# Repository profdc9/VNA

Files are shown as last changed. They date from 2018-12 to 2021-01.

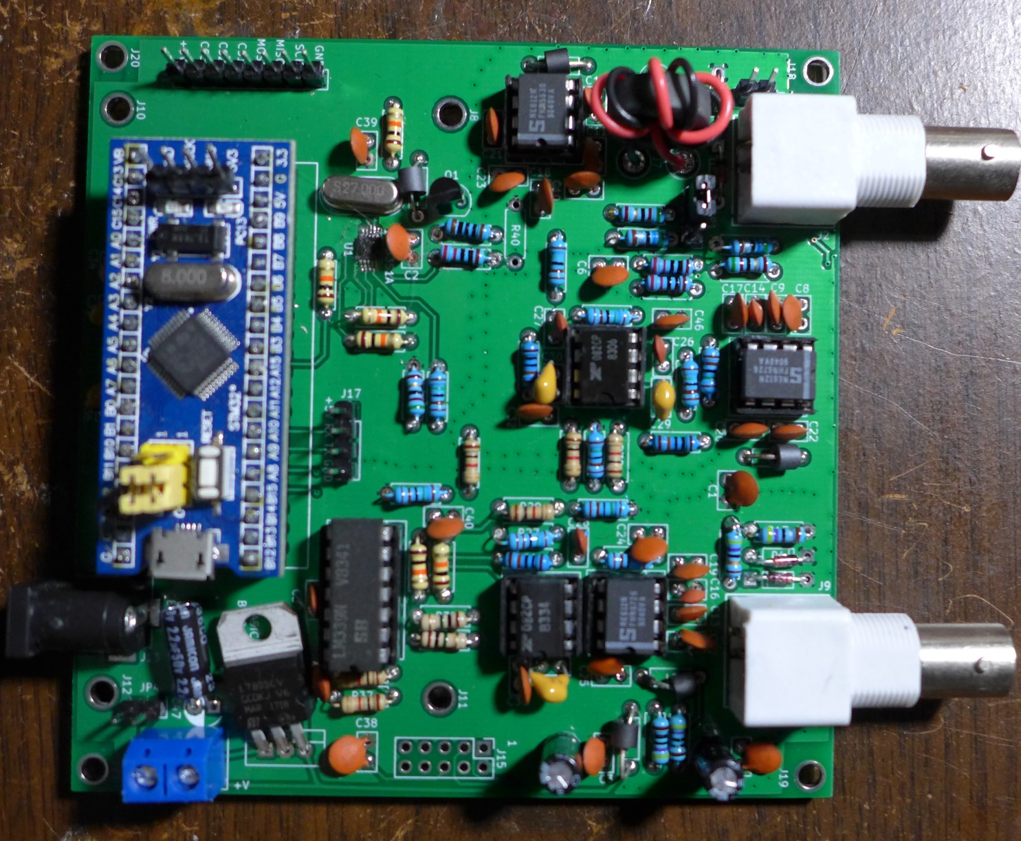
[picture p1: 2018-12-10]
doc/vna-assembled-board.jpg

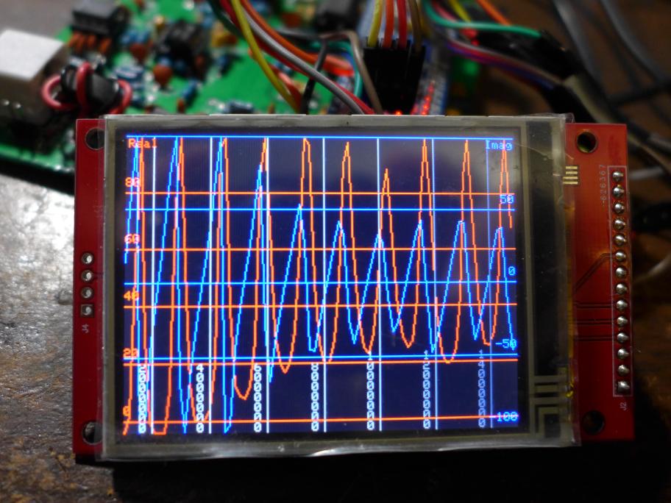
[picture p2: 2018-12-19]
doc/vna-impedance-display.jpg

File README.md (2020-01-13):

This a project to create a Vector Network Analyzer based on the EU1KY antenna tuner that can be reconfigured for different needs.  This material is copyrighted by Daniel Marks (KW4TI) and licensed under the Creative Commons License CC-BY-SA 4.0.  The software is licensed under the zlib license.  These are open source licenses that permit commercial use, modification and redistribution with attribution, and require licensees to assume all risk for using the copyrighted materials.

Currently what is on this github are the Kicad files for the VNA and the software.  The software uses the "stm32duino" extension to the Arduino IDE.  The Arduino IDE can be downloaded from

https://www.arduino.cc/en/Main/Software

The stm32duino software can be installed using the instructions on the stm32duino web site

https://github.com/rogerclarkmelbourne/Arduino_STM32/wiki/Installation

which involves (at this time) downloading the git archive for the stm32duino and placing it under the "hardware" folder in your Arduino folder.

There are several Arduino libraries that are required for the SI5351A frequency synthesizer chip, ILI9341 TFT display module, and XPT2046 touchscreen controller.  These are provided for your use under the "libraries" directory of this archive, but may not be the most recent versions.  You could copy these directories into the "libraries" folder in your Arduino directory.

---------------------------------

The VNA may be used with or without a touchscreen.  If a touchscreen it used, it should be compiled with the "VNA_TOUCHSCREEN" defined in VNA.h.  If you do not have a touchscreen, you can ground the pin PB13 and it will start up without a touchscreen, only appearing a USB CDC serial port device.  You can then type "HELP" to see the list of commands.

The touchscreen used is a 2.8" touchscreen with a SPI interface to the ILI9341 and XPT2046.  These are commonly available at a low price.  To connect it to the SPI interface connector header "J1" on the board, use a 14 pin IDC ribbon cable.

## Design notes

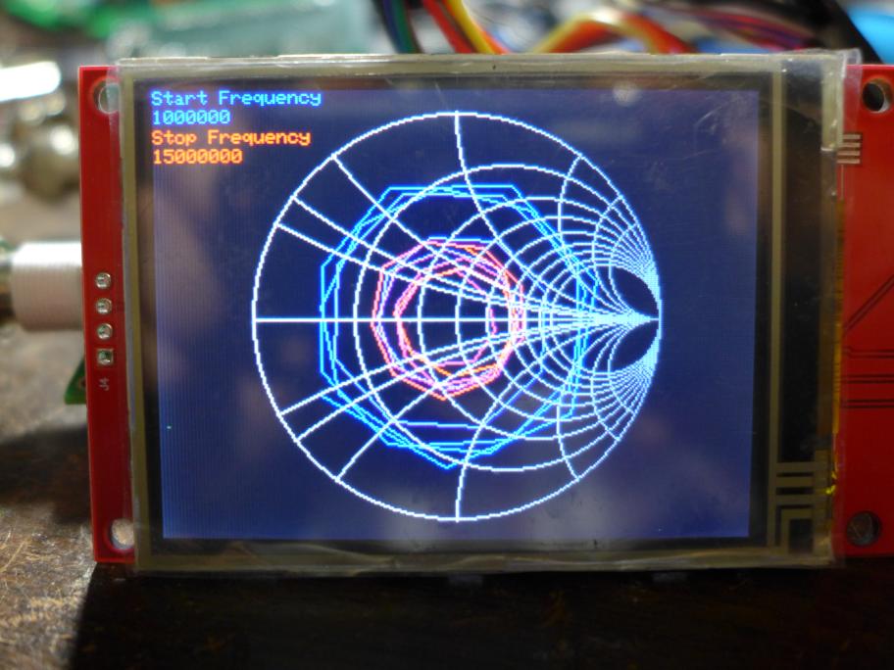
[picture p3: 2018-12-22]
doc/vna-smith-chart-2.jpg

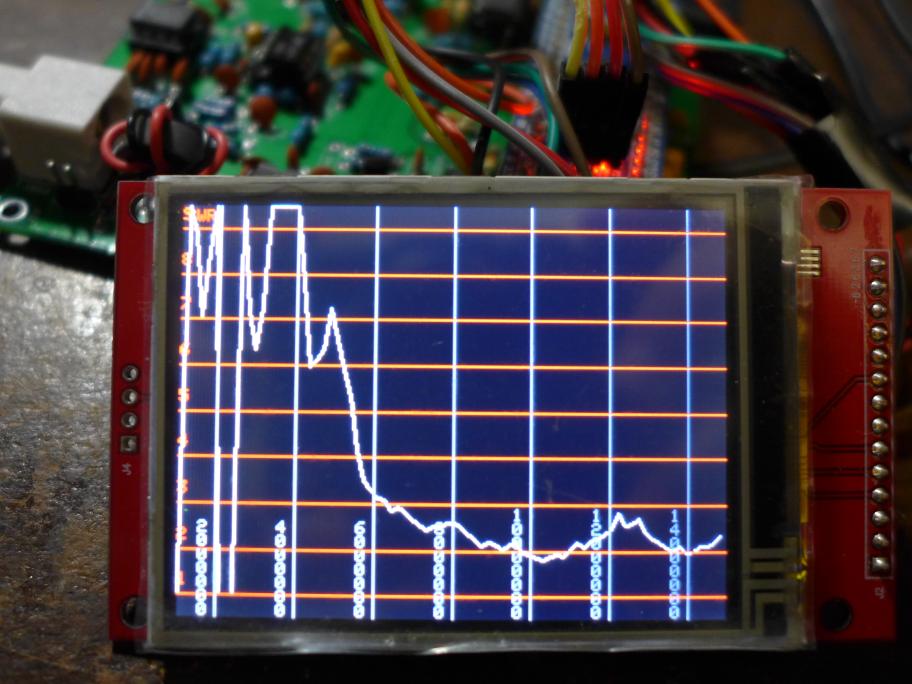
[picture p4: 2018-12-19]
doc/vna-swr-display.jpg

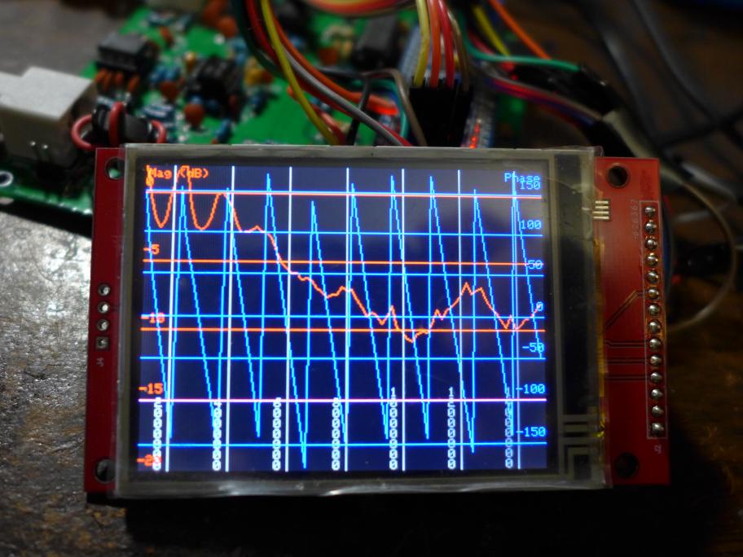
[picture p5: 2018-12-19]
doc/vna-s11-display.jpg

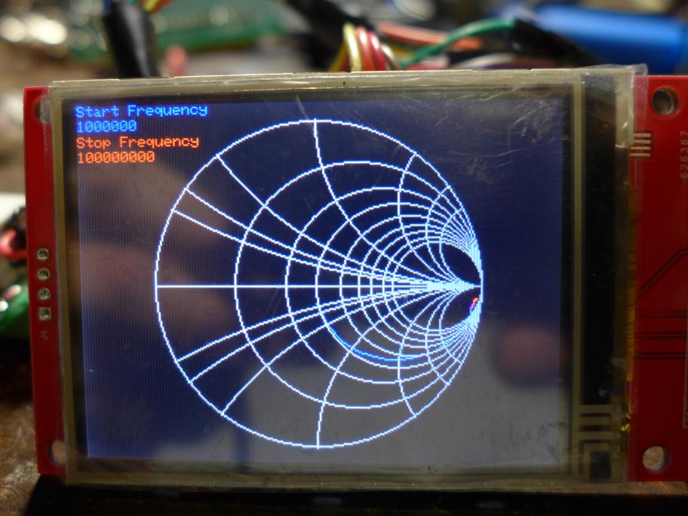
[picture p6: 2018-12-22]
doc/vna-smith-chart-1.jpg

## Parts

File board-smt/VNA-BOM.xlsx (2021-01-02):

Comment | Designator | Footprint | LCSC
330 pF | C15,C14,C16 | Capacitors_SMD:C_0805_HandSoldering | C51207
10 nF | C27,C26,C28 | Capacitors_SMD:C_0805_HandSoldering | C1710
100 nF | C3,C2,C5,C6,C1,C46,C48,C39,C40,C41,C43,C42,C50,C51,C53,C59,C57,C56,C55,C54,C23,C10,C11,C21,C18,C32,C22,C8,C9,C20,C17,C25,C12,C13,C24,C19,C33,C37 | Capacitors_SMD:C_0805_HandSoldering | C49678
68 pF | C30,C29,C31 | Capacitors_SMD:C_0805_HandSoldering | C1834
1 nF | C34,C36,C35 | Capacitors_SMD:C_0805_HandSoldering | C46653
22 uF | C38,C44 | Capacitors_SMD:C_1210_HandSoldering
1000 uF | C4,C7 | Capacitors_SMD:CP_Elec_8x10.5
4.7 uF | C45 | Capacitors_SMD:CP_Elec_4x4.5
1 uF | C47 | Capacitors_SMD:C_0805_HandSoldering | C28323
10 uF | C49 | Capacitors_SMD:CP_Elec_4x4.5
100 uF | C52 | Capacitors_SMD:CP_Elec_4x4.5
22 pF | C60,C58 | Capacitors_SMD:C_0805_HandSoldering | C1804
BAV99 | D1,D2 | TO_SOT_Packages_SMD:SOT-23
SS14 | D5,D3,D4 | Diodes_SMD:D_SMA | C2480
MMSZ5232B | D6 | Diodes_SMD:D_MiniMELF | C8062
LED | D7 | LEDs:LED_0805 | C84256
Conn_02x07_Odd_Even | J1 | Pin_Headers:Pin_Header_Straight_2x07_Pitch2.54mm
Conn_01x04 | J10,J3 | Pin_Headers:Pin_Header_Straight_1x04_Pitch2.54mm
Barrel_Jack | J13 | Connectors:BARREL_JACK
Conn_01x02 | J15 | Connectors_Molex:Molex_KK-6410-02_02x2.54mm_Straight
Conn_01x01 | J18,J19,J20,J21,J8,J11,J14,J16 | Connectors:1pin
Conn_Coaxial | J2,J9 | VNA:Amphenol_RF_SMA_132289
USB_B | J24 | Connectors:USB_B
Jumper_NC_Small | JP3,JP2,JP1,JP7 | Pin_Headers:Pin_Header_Straight_1x02_Pitch2.54mm
Jumper_NC_Dual | JP5 | Pin_Headers:Pin_Header_Straight_1x03_Pitch2.54mm
Ferrite_Bead_Small | L1,L2,L6,L7,L4,L3,L5 | Inductors_SMD:L_0805_HandSoldering | C1015
10 uH | L10,L9 | Inductors_SMD:L_7.3x7.3_H4.5
2SC3356 | Q3 | TO_SOT_Packages_SMD:SOT-23 | C9659
10k | R1,R2,R38,R39,R55,R53,R54,R56,R64,R7,R36,R10,R37 | Resistors_SMD:R_0805_HandSoldering | C17414
100R | R12,R40,R59,R61,R62,R65 | Resistors_SMD:R_0805_HandSoldering | C17408
51R | R14,R16,R44,R46 | Resistors_SMD:R_0805_HandSoldering | C17738
220R | R15,R51,R58 | Resistors_SMD:R_0805_HandSoldering | C17557
100k | R23,R22,R24 | Resistors_SMD:R_0805_HandSoldering | C17407
1k | R3,R42,R28,R32,R29 | Resistors_SMD:R_0805_HandSoldering | C17513
2k2 | R30,R33,R31 | Resistors_SMD:R_0805_HandSoldering | C17520
1M | R34,R35 | Resistors_SMD:R_0805_HandSoldering | C17514
680R | R4 | Resistors_SMD:R_0805_HandSoldering | C17798
22R | R47,R48,R68 | Resistors_SMD:R_0805_HandSoldering | C17561
47R | R5,R11,R18 | Resistors_SMD:R_0805_HandSoldering | C17714
0R | R50,R41,R63 | Resistors_SMD:R_0805_HandSoldering | C17477
270R | R57 | Resistors_SMD:R_0805_HandSoldering | C17590
4R7 | R6,R13,R17 | Resistors_SMD:R_0805_HandSoldering | C17675
68R | R60 | Resistors_SMD:R_0805_HandSoldering | C17802
120R | R66,R67 | Resistors_SMD:R_0805_HandSoldering | C17437
1k5 | R9,R43,R45,R49,R52,R8,R20,R26,R19,R25,R21,R27 | Resistors_SMD:R_0805_HandSoldering | C4310
SW_DPDT_x2 | SW1 | Connectors_Molex:Molex_KK-6410-06_06x2.54mm_Straight
SW_DIP_x01 | SW2 | Buttons_Switches_THT:SW_PUSH_6mm
SI5351A | U1,U12 | Housings_SSOP:MSOP-10_3x3mm_Pitch0.5mm
MT3608 | U10 | TO_SOT_Packages_SMD:SOT-23-6
CN3052 | U11 | Housings_SOIC:TI_SO-PowerPAD-8
MicroSD_SPI_CD | U13 | VNA:GCT-MEM2055-00-190-01-A
STM32F103C8T6 | U14 | Housings_QFP:LQFP-48_7x7mm_Pitch0.5mm | C8304
LM393 | U2 | Housings_SOIC:SOIC-8_3.9x4.9mm_Pitch1.27mm | C7955
SA612 | U4,U3,U5 | Housings_SOIC:SOIC-8_3.9x4.9mm_Pitch1.27mm
LM358 | U6,U7 | Housings_SOIC:SOIC-8_3.9x4.9mm_Pitch1.27mm | C7950
AMS1117-3V3 | U8 | TO_SOT_Packages_SMD:SOT-223 | C6186
78M05_TO252 | U9 | TO_SOT_Packages_SMD:TO-252-3_TabPin2 | C58069
25 MHz | Y1 | Crystals:Crystal_SMD_3225-4pin_3.2x2.5mm_HandSoldering | C9006
8 MHz | Y2 | Crystals:Crystal_SMD_5032-2pin_5.0x3.2mm_HandSoldering | C115962

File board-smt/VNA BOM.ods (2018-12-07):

Source: | E:/VNA/board/VNA.sch
Date: | 12/5/2018 11:00:17 AM
Tool: | Eeschema 4.0.7
Component Count: | 127
Ref | Value | Footprint
C1 | 100 nF | Capacitors_THT:C_Disc_D5.0mm_W2.5mm_P2.50mm
C2 | 100 nF | Capacitors_THT:C_Disc_D5.0mm_W2.5mm_P2.50mm
C3 | 100 nF | Capacitors_THT:C_Disc_D5.0mm_W2.5mm_P2.50mm
C4 | 100 uF | Capacitors_THT:CP_Radial_D5.0mm_P2.50mm
C5 | 100 nF | Capacitors_THT:C_Disc_D5.0mm_W2.5mm_P2.50mm
C6 | 100 nF | Capacitors_THT:C_Disc_D5.0mm_W2.5mm_P2.50mm
C7 | 10 uF | Capacitors_THT:CP_Radial_D5.0mm_P2.50mm
C8 | 100 nF | Capacitors_THT:C_Disc_D5.0mm_W2.5mm_P2.50mm
C9 | 100 nF | Capacitors_THT:C_Disc_D5.0mm_W2.5mm_P2.50mm
C10 | 100 nF | Capacitors_THT:C_Disc_D5.0mm_W2.5mm_P2.50mm
C11 | 100 nF | Capacitors_THT:C_Disc_D5.0mm_W2.5mm_P2.50mm
C12 | 100 nF | Capacitors_THT:C_Disc_D5.0mm_W2.5mm_P2.50mm
C13 | 100 nF | Capacitors_THT:C_Disc_D5.0mm_W2.5mm_P2.50mm
C14 | 330 pF | Capacitors_THT:C_Disc_D5.0mm_W2.5mm_P2.50mm
C15 | 330 pF | Capacitors_THT:C_Disc_D5.0mm_W2.5mm_P2.50mm
C16 | 330 pF | Capacitors_THT:C_Disc_D5.0mm_W2.5mm_P2.50mm
C17 | 100 nF | Capacitors_THT:C_Disc_D5.0mm_W2.5mm_P2.50mm
C18 | 100 nF | Capacitors_THT:C_Disc_D5.0mm_W2.5mm_P2.50mm
C19 | 100 nF | Capacitors_THT:C_Disc_D5.0mm_W2.5mm_P2.50mm
C20 | 100 nF | Capacitors_THT:C_Disc_D5.0mm_W2.5mm_P2.50mm
C21 | 100 nF | Capacitors_THT:C_Disc_D5.0mm_W2.5mm_P2.50mm
C22 | 100 nF | Capacitors_THT:C_Disc_D5.0mm_W2.5mm_P2.50mm
C23 | 100 nF | Capacitors_THT:C_Disc_D5.0mm_W2.5mm_P2.50mm
C24 | 100 nF | Capacitors_THT:C_Disc_D5.0mm_W2.5mm_P2.50mm
C25 | 100 nF | Capacitors_THT:C_Disc_D5.0mm_W2.5mm_P2.50mm
C26 | 10 nF | Capacitors_THT:C_Disc_D5.0mm_W2.5mm_P2.50mm
C27 | 10 nF | Capacitors_THT:C_Disc_D5.0mm_W2.5mm_P2.50mm
C28 | 10 nF | Capacitors_THT:C_Disc_D5.0mm_W2.5mm_P2.50mm
C29 | 68 pF | Capacitors_THT:C_Disc_D5.0mm_W2.5mm_P2.50mm
C30 | 68 pF | Capacitors_THT:C_Disc_D5.0mm_W2.5mm_P2.50mm
C31 | 68 pF | Capacitors_THT:C_Disc_D5.0mm_W2.5mm_P2.50mm
C32 | 100 nF | Capacitors_THT:C_Disc_D5.0mm_W2.5mm_P2.50mm
C33 | 100 nF | Capacitors_THT:C_Disc_D5.0mm_W2.5mm_P2.50mm
C34 | 1 nF | Capacitors_THT:C_Disc_D5.0mm_W2.5mm_P2.50mm
C35 | 1 nF | Capacitors_THT:C_Disc_D5.0mm_W2.5mm_P2.50mm
C36 | 1 nF | Capacitors_THT:C_Disc_D5.0mm_W2.5mm_P2.50mm
C37 | 100 nF | Capacitors_THT:C_Disc_D5.0mm_W2.5mm_P2.50mm
C38 | 100 nF | Capacitors_THT:C_Disc_D5.0mm_W2.5mm_P2.50mm
C39 | 100 nF | Capacitors_THT:C_Disc_D5.0mm_W2.5mm_P2.50mm
C40 | 100 nF | Capacitors_THT:C_Disc_D5.0mm_W2.5mm_P2.50mm
C46 | 100 nF | Capacitors_THT:C_Disc_D5.0mm_W2.5mm_P2.50mm
C47 | 100 uF | Capacitors_THT:CP_Radial_D5.0mm_P2.50mm
C48 | 100 nF | Capacitors_THT:C_Disc_D5.0mm_W2.5mm_P2.50mm
D1 | 1N4148 | Diodes_THT:D_DO-35_SOD27_P7.62mm_Horizontal
D2 | 1N4148 | Diodes_THT:D_DO-35_SOD27_P7.62mm_Horizontal
D3 | 1N4148 | Diodes_THT:D_DO-35_SOD27_P7.62mm_Horizontal
D4 | 1N4148 | Diodes_THT:D_DO-35_SOD27_P7.62mm_Horizontal
J1 | Conn_01x08 | Pin_Headers:Pin_Header_Straight_1x08_Pitch2.54mm
J2 | Conn_Coaxial | w_conn_rf:bnc_90_1-1337543-0
J3 | Conn_01x01 | Connectors:1pin
J4 | Conn_01x01 | Connectors:1pin
J5 | Conn_01x01 | Connectors:1pin
J6 | Conn_01x01 | Connectors:1pin
J7 | Conn_01x01 | Connectors:1pin
J8 | Conn_01x01 | Connectors:1pin
J9 | Conn_Coaxial | w_conn_rf:bnc_90_1-1337543-0
J10 | Conn_01x01 | Connectors:1pin
J11 | Conn_01x01 | Connectors:1pin
J12 | Conn_01x01 | Connectors:1pin
J13 | Barrel_Jack | Connectors:BARREL_JACK
J15 | Conn_02x05_Odd_Even | Pin_Headers:Pin_Header_Straight_2x05_Pitch2.54mm
J17 | Conn_01x04 | Pin_Headers:Pin_Header_Straight_1x04_Pitch2.54mm
J18 | Conn_01x01 | Connectors:1pin
J19 | Conn_01x01 | Connectors:1pin
J20 | Conn_01x01 | Connectors:1pin
J21 | Conn_01x01 | Connectors:1pin
J22 | Conn_01x02 | Connectors_Terminal_Blocks:TerminalBlock_bornier-2_P5.08mm
JP1 | Jumper_NC_Dual | Pin_Headers:Pin_Header_Straight_1x03_Pitch2.54mm
JP3 | Jumper_NC_Small | Pin_Headers:Pin_Header_Straight_1x02_Pitch2.54mm
JP4 | Jumper_NC_Small | Pin_Headers:Pin_Header_Straight_1x02_Pitch2.54mm
L1 | Ferrite_Bead_Small | Inductors_THT:L_Axial_L5.3mm_D2.2mm_P7.62mm_Horizontal_Vishay_IM-1
L2 | Ferrite_Bead_Small | Inductors_THT:L_Axial_L5.3mm_D2.2mm_P7.62mm_Horizontal_Vishay_IM-1
L3 | Ferrite_Bead_Small | Inductors_THT:L_Axial_L5.3mm_D2.2mm_P7.62mm_Horizontal_Vishay_IM-1
L4 | Ferrite_Bead_Small | Inductors_THT:L_Axial_L5.3mm_D2.2mm_P7.62mm_Horizontal_Vishay_IM-1
L5 | Ferrite_Bead_Small | Inductors_THT:L_Axial_L5.3mm_D2.2mm_P7.62mm_Horizontal_Vishay_IM-1
Q1 | SS9018 | TO_SOT_Packages_THT:TO-92_Molded_Narrow
R1 | 10k | Resistors_THT:R_Axial_DIN0207_L6.3mm_D2.5mm_P7.62mm_Horizontal
R2 | 10k | Resistors_THT:R_Axial_DIN0207_L6.3mm_D2.5mm_P7.62mm_Horizontal
R3 | 470R | Resistors_THT:R_Axial_DIN0207_L6.3mm_D2.5mm_P7.62mm_Horizontal
R4 | 470R | Resistors_THT:R_Axial_DIN0207_L6.3mm_D2.5mm_P7.62mm_Horizontal
R5 | 220R | Resistors_THT:R_Axial_DIN0207_L6.3mm_D2.5mm_P7.62mm_Horizontal
R6 | 5R1 | Resistors_THT:R_Axial_DIN0207_L6.3mm_D2.5mm_P7.62mm_Horizontal
R7 | 10k | Resistors_THT:R_Axial_DIN0207_L6.3mm_D2.5mm_P7.62mm_Horizontal
R8 | 51R | Resistors_THT:R_Axial_DIN0207_L6.3mm_D2.5mm_P7.62mm_Horizontal
R9 | 1.5k | Resistors_THT:R_Axial_DIN0207_L6.3mm_D2.5mm_P7.62mm_Horizontal
R10 | 10k | Resistors_THT:R_Axial_DIN0207_L6.3mm_D2.5mm_P7.62mm_Horizontal
R11 | 220R | Resistors_THT:R_Axial_DIN0207_L6.3mm_D2.5mm_P7.62mm_Horizontal
R12 | 51R | Resistors_THT:R_Axial_DIN0207_L6.3mm_D2.5mm_P7.62mm_Horizontal
R13 | 5R1 | Resistors_THT:R_Axial_DIN0207_L6.3mm_D2.5mm_P7.62mm_Horizontal
R14 | 51R | Resistors_THT:R_Axial_DIN0207_L6.3mm_D2.5mm_P7.62mm_Horizontal
R15 | 100R | Resistors_THT:R_Axial_DIN0207_L6.3mm_D2.5mm_P7.62mm_Horizontal
R16 | 100R | Resistors_THT:R_Axial_DIN0207_L6.3mm_D2.5mm_P7.62mm_Horizontal
R17 | 4R7 | Resistors_THT:R_Axial_DIN0207_L6.3mm_D2.5mm_P7.62mm_Horizontal
R18 | 47R | Resistors_THT:R_Axial_DIN0207_L6.3mm_D2.5mm_P7.62mm_Horizontal
R19 | 1k5 | Resistors_THT:R_Axial_DIN0207_L6.3mm_D2.5mm_P7.62mm_Horizontal
R20 | 1k5 | Resistors_THT:R_Axial_DIN0207_L6.3mm_D2.5mm_P7.62mm_Horizontal
R21 | 1k5 | Resistors_THT:R_Axial_DIN0207_L6.3mm_D2.5mm_P7.62mm_Horizontal
R22 | 100k | Resistors_THT:R_Axial_DIN0207_L6.3mm_D2.5mm_P7.62mm_Horizontal
R23 | 100k | Resistors_THT:R_Axial_DIN0207_L6.3mm_D2.5mm_P7.62mm_Horizontal
R24 | 100k | Resistors_THT:R_Axial_DIN0207_L6.3mm_D2.5mm_P7.62mm_Horizontal
R25 | 1k5 | Resistors_THT:R_Axial_DIN0207_L6.3mm_D2.5mm_P7.62mm_Horizontal
R26 | 1k5 | Resistors_THT:R_Axial_DIN0207_L6.3mm_D2.5mm_P7.62mm_Horizontal
R27 | 1k5 | Resistors_THT:R_Axial_DIN0207_L6.3mm_D2.5mm_P7.62mm_Horizontal
R28 | 1k | Resistors_THT:R_Axial_DIN0207_L6.3mm_D2.5mm_P7.62mm_Horizontal
R29 | 1k | Resistors_THT:R_Axial_DIN0207_L6.3mm_D2.5mm_P7.62mm_Horizontal
R30 | 1k5 | Resistors_THT:R_Axial_DIN0207_L6.3mm_D2.5mm_P7.62mm_Horizontal
R31 | 1k5 | Resistors_THT:R_Axial_DIN0207_L6.3mm_D2.5mm_P7.62mm_Horizontal
R32 | 1k | Resistors_THT:R_Axial_DIN0207_L6.3mm_D2.5mm_P7.62mm_Horizontal
R33 | 1k5 | Resistors_THT:R_Axial_DIN0207_L6.3mm_D2.5mm_P7.62mm_Horizontal
R34 | 1M | Resistors_THT:R_Axial_DIN0207_L6.3mm_D2.5mm_P7.62mm_Horizontal
R35 | 1M | Resistors_THT:R_Axial_DIN0207_L6.3mm_D2.5mm_P7.62mm_Horizontal
R36 | 1k | Resistors_THT:R_Axial_DIN0207_L6.3mm_D2.5mm_P7.62mm_Horizontal
R37 | 1k | Resistors_THT:R_Axial_DIN0207_L6.3mm_D2.5mm_P7.62mm_Horizontal
R38 | 1k | Resistors_THT:R_Axial_DIN0207_L6.3mm_D2.5mm_P7.62mm_Horizontal
R39 | 1k | Resistors_THT:R_Axial_DIN0207_L6.3mm_D2.5mm_P7.62mm_Horizontal
R40 | NC | Resistors_THT:R_Axial_DIN0207_L6.3mm_D2.5mm_P7.62mm_Horizontal
R41 | 1k | Resistors_THT:R_Axial_DIN0207_L6.3mm_D2.5mm_P7.62mm_Horizontal
U1 | SI5351A | Housings_SSOP:MSOP-10_3x3mm_Pitch0.5mm
U2 | LM339 | Housings_DIP:DIP-14_W7.62mm_Socket
U3 | SA612 | Housings_DIP:DIP-8_W7.62mm_Socket
U4 | SA612 | Housings_DIP:DIP-8_W7.62mm_Socket
U5 | SA612 | Housings_DIP:DIP-8_W7.62mm_Socket
U6 | TL082 | Housings_DIP:DIP-8_W7.62mm_Socket
U7 | TL082 | Housings_DIP:DIP-8_W7.62mm_Socket
U9 | LM7805_TO220 | TO_SOT_Packages_THT:TO-220-3_Vertical
UB1 | BLUEPILL | VNA:BLUEPILL
Y1 | 27 MHz | Crystals:Crystal_HC49-U_Vertical

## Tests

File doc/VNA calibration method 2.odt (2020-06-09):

Six-point calibration method of VNA-O-Mizer by Daniel Marks KW4TI

The raw data output of the VNA is captured using the IMACQ command. The IMACQ command has three parameters:

IMACQ <# frequencies> <start frequency> <end frequency>

which captures the raw data for <# frequencies> from <start frequency> to <end frequency>. The result is in the following format, which is the raw data captured using quadrature demodulated samples:

<frequency>,<port 1 in-phase reference>,<port 1 quadrature reference>, <port 1 in-phase voltage>,<port 1 quadrature voltage current>, <port 2 in-phase current>,<port 2 quadrature current>

The number of averages which influences the dynamic range is set by

AVERAGES <# averages> <timeout in ms>

where the default number of averages is 64 for a 40 to 45 dB dynamic range, which increases to about 50 to 55 dB for 1000 averages which slows down the acquisition.

The calibration method is as follows. Three complex numbers are formed from this data:

It is assumed that the actual voltage and currents at port 1 are the linear combinations of and :

We can form the estimated impedance at the port by dividing these:

with

If we place three impedances , , and on the port and measure the corresponding reference and voltages , , and port voltages , , . From these , , and are computed. Then B, C, and D can be solved for:

If we simplify this so that for an open circuit and are measured, for a short circuit and are measured, and for a termination of and are measured, from which , , and . Then B, C, and D can be solved for:

When you actually measure an impedance at channel 1, you will measure a complex-valued reference sample and port voltage sample These are divided to form . The actual impedance is then calibrated from the following bilinear transformation

where B, C, D, are the three complex-valued calibration parameters for port 1. These parameters are captured for each frequency.

For port two calibration, first the isolation between port 1 and port 2 is found. The raw complex-valued current at port 2 is . The isolation is measured at port 2 during the port 1 load-circuit measurement step when the termination is on port 1:

The total amount of signal leaking from port 1 to 2 scales with the number of averages, so the calibration is stored normalized by the number of averages.

To calibrate the impedance and gain at port 2, port 1 is connected to port 2. The raw current is sampled at port 2 . At the same time, the samples of reference and port voltage are measured at port 1. Then the following two parameters are calculated for port 2:

To calculate the complex-valued , use

from which SWR, dB, and degrees may be determined.

To calculate

To calculate the thru impedance in series impedance mode

and the thru impedance in shunt mode

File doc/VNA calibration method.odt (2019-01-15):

Six-point calibration method of VNA-O-Mizer by Daniel Marks KW4TI

The raw data output of the VNA is captured using the IMACQ command. The IMACQ command has three parameters:

IMACQ <# frequencies> <start frequency> <end frequency>

which captures the raw data for <# frequencies> from <start frequency> to <end frequency>. The result is in the following format, which is the raw data captured using quadrature demodulated samples:

<frequency>,<channel 1 in phase voltage>,<channel 1 quadrature voltage>, <channel 1 in phase current>,<channel 1 quadrature current>, <channel 2 in phase current>,<channel 2 quadrature current>

Three complex numbers are formed from this data (which are not actual voltage and current, but will be used to calibrate it):

The number of averages which influences the dynamic range is set by

AVERAGES <# averages> <timeout in ms>

where the default number of averages is 64 for a 40 to 45 dB dynamic range, which increases to about 50 to 55 dB for 1000 averages which slows down the acquisition.

The calibration method is as follows:

For the one-port cal, capture the raw data for an open, short, and load (usually 50 ohms) fort channel 1. These will form six complex numbers , , , , , .

Divide these to form three trial impedances using complex division:

, ,

When you actually measure an impedance at channel 1, you will measure a complex-valued voltage and current which is and . These are divided to form . The actual impedance is then calibrated from the following bilinear transformation

where B, C, D, are the three complex-valued calibration parameters for port 1. These parameters are captured for each frequency. These are calculated using:

where is the characteristic impedance (usually 50 ohms)

For port two calibration, first the isolation between port 1 and port 2 is found. The raw complex-valued current at port 2 is . I measure the current at port 2 during the port 1 short-circuit measurement step:

The total amount of signal leaking from port 1 to 2 scales with the number of averages, so the calibration is stored normalized by the number of averages.

To calibrate the impedance and gain at port 2, port 1 is connected to port 2. The raw current at port 2 is . The calibrated voltage and current at port 2 from port 1 are calculated from the raw samples and when they are connected together by

and the following two parameters are captured:

To calculate the complex-valued , use

from which SWR, dB, and degrees may be determined.

To calculate

To calculate the thru impedance in series impedance mode

and the thru impedance in shunt mode

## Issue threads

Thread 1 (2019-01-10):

What  to use as a RF Choke across J4-J7

geekbozu, 2019-01-10:
What to use and how to wire up this choke for decent performance?

profdc9, 2019-02-19:
Use a small toroid something like two stacked FT50-43 four turns through it, with J4-J6 and J5-J7 connected together through the choke.  I used a ferrite that was like a FT50-75 and that seemed to work as well.  75/77 works better at lower frequencies, 43 on higher, but it's a common mode choke so its pretty tolerant.

geekbozu, 2019-02-19:
Would there be any issues just leaving it out? I feel like this may be unnecessary/really hurting higher frequency performance. Maybe adding a 500mhz LowPass would perform similarly with out causing Loss on the higher frequencies?

profdc9, 2019-02-21:
The common mode choke is needed to generate a voltage on the current sense
resistor proportional to the current in the port.  The VNA will not
function without it.  Even a simple choke is better than none.  Some have
actually used the ferrite bead taken from an EMI suppressor in a cable.

Dan

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

geekbozu, 2019-03-02:
I had a conversation with EU1KY my problem has been solved. Will close for now and respond with info after testing.

Closed 2019-03-02.

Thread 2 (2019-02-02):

Principle of operation

andrey-belokon, 2019-02-02:
Hi,
As I can see you implemented magnitude/phase measurement without sin/cos multiplication which used in EU1KY analyzer. Can you describe principle of operation for used method or give me URL if this information found somewhere in web. Thanks
73! Andrew

profdc9, 2019-05-27:
The signal is recorded at 4 times its frequency.  The LM339 comparator provides a clock so this can be done accurately.  So for example for a 10 kHz intermediate frequency, you sample at 40 kHz.  Then each successive sample is multiplied by +1, +j, -1, -j, because these are the four phases, which is just addition/subtraction to the real or imaginary part.  So to measure the in phase/quadrature component, only integer arithmetic is required in this case.

Closed 2019-05-27.

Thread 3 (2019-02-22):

Drill file misalignment

gerryk, 2019-02-22:
I submitted the SMD Gerbers for manufacture & the manufacturer replied as follows:

"As the attached pictures ,those NPT holes will drill off lines . "

Image attached.
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

gerryk, 2019-02-25:
VNA-NPTH drill file seems extraneous

profdc9, 2019-05-17:
It is extraneous, it is accidentally there from another project.  It will be deleted.

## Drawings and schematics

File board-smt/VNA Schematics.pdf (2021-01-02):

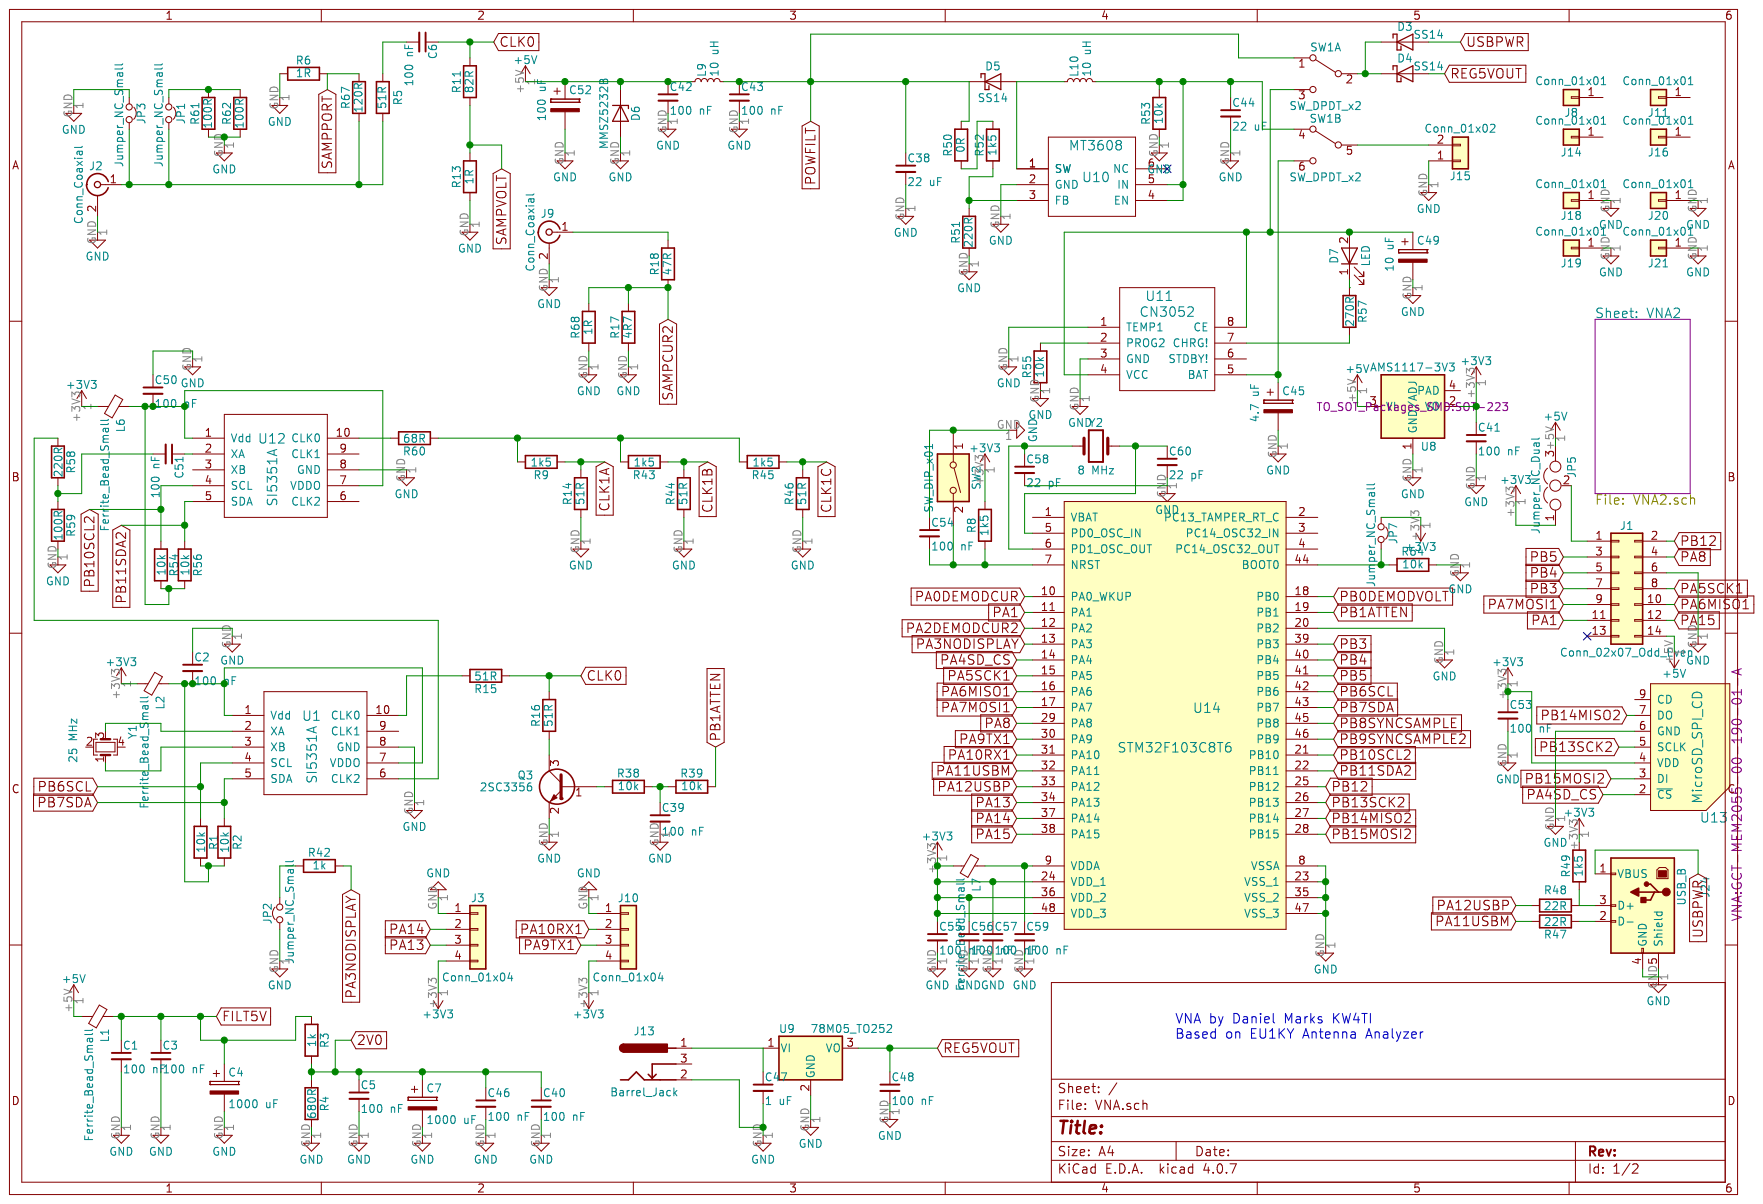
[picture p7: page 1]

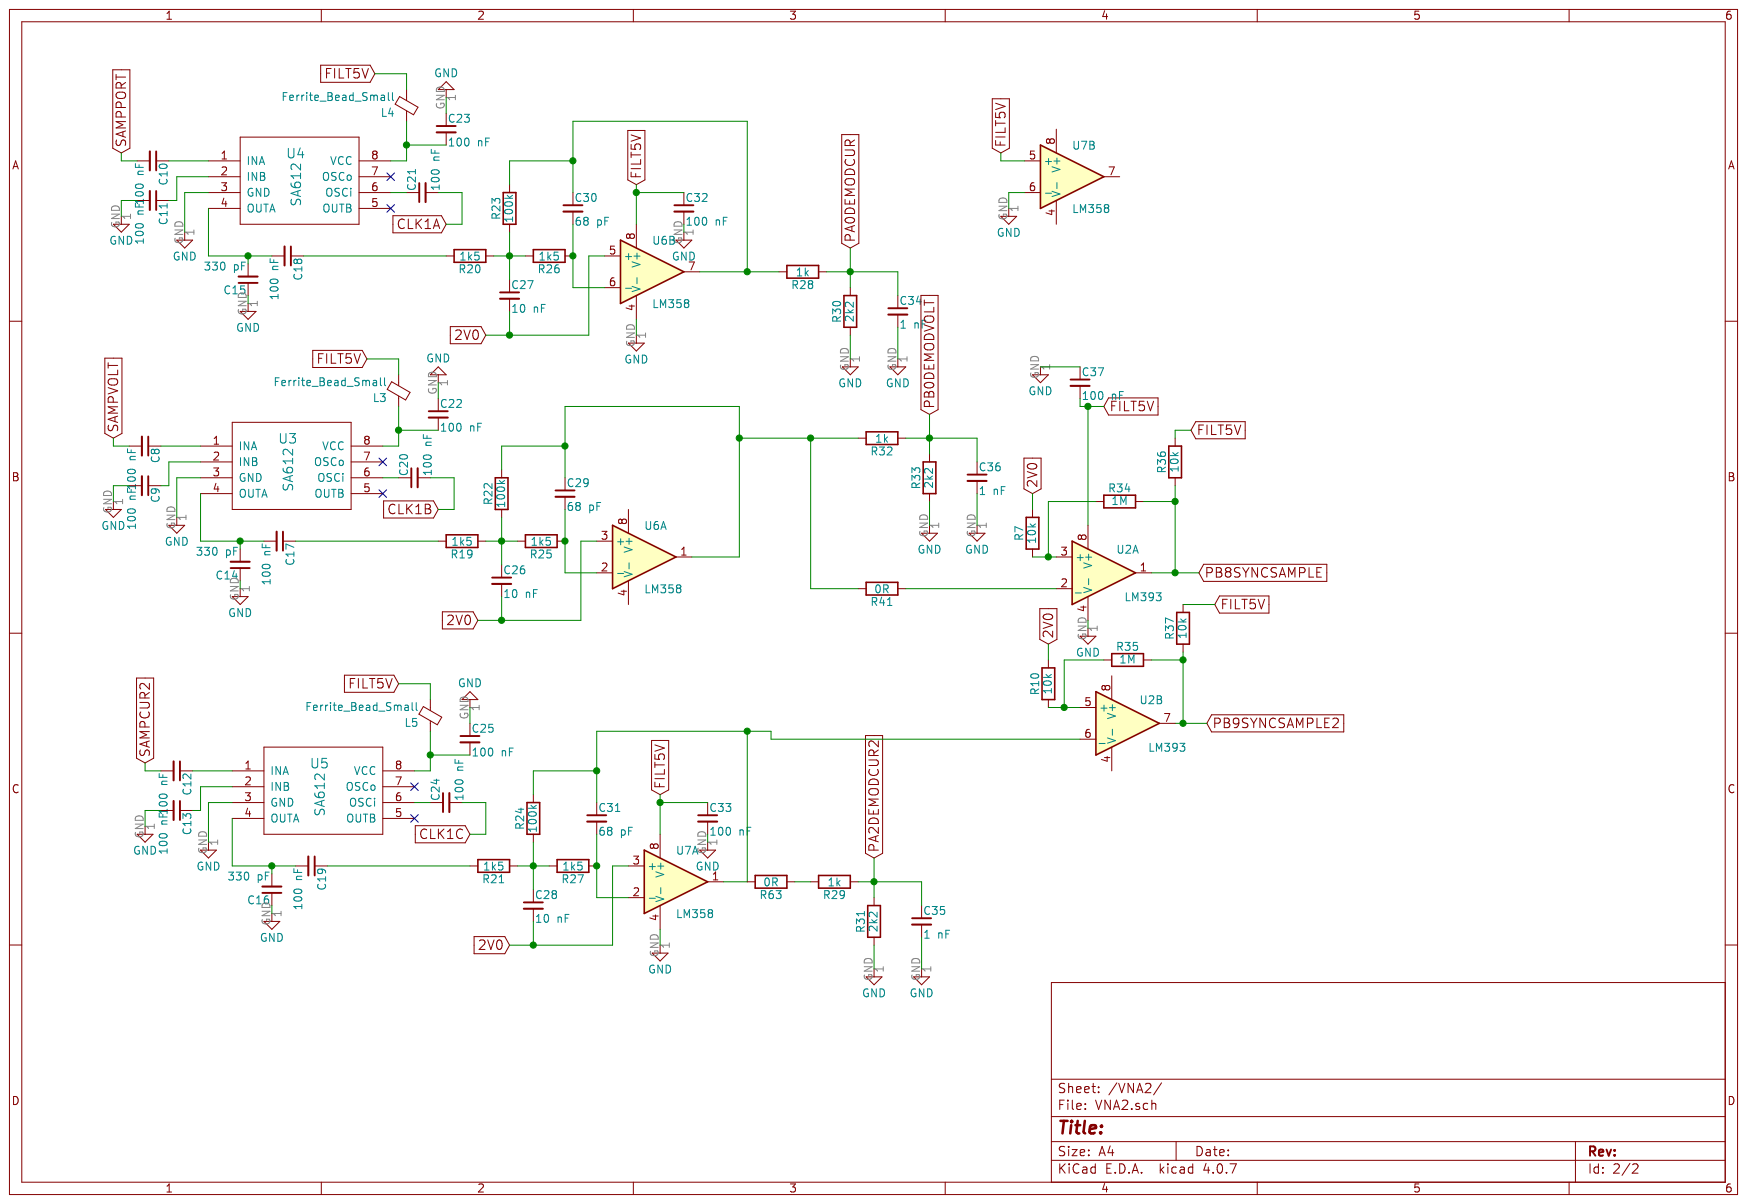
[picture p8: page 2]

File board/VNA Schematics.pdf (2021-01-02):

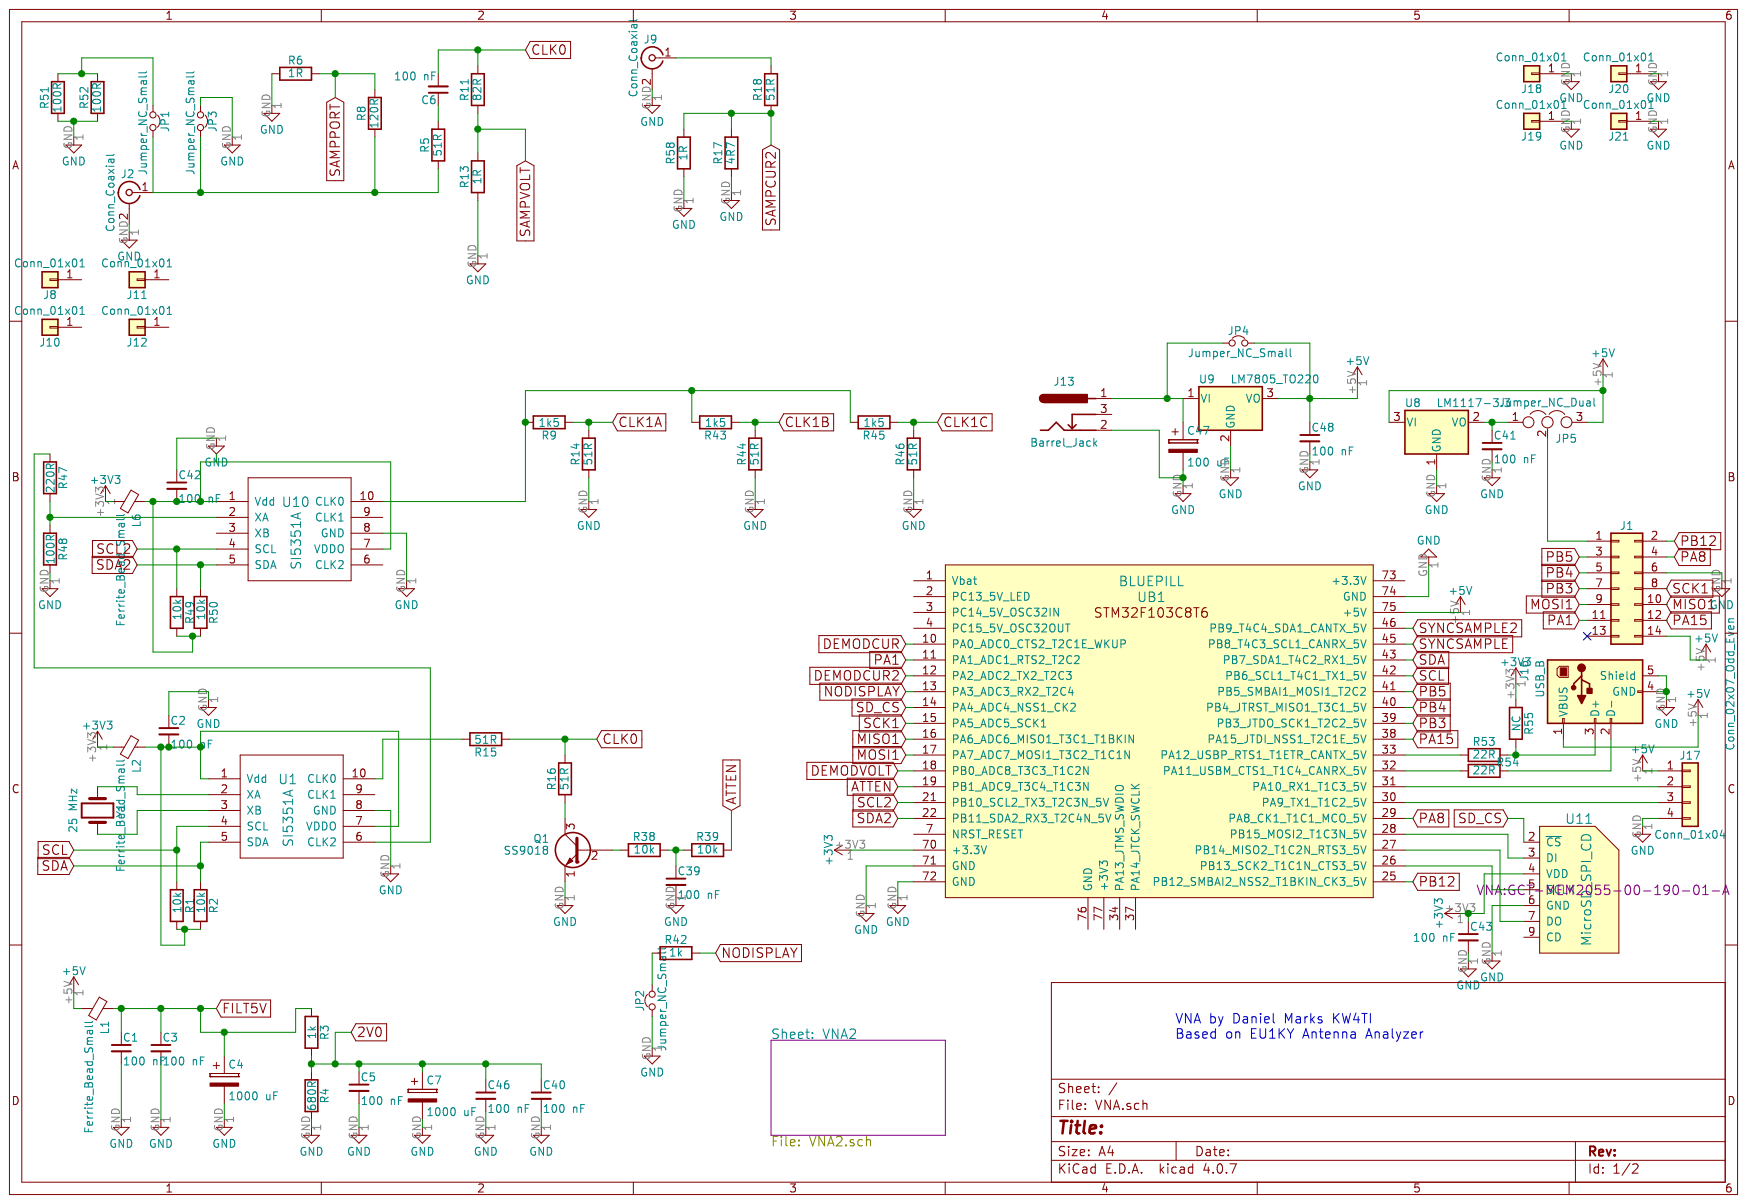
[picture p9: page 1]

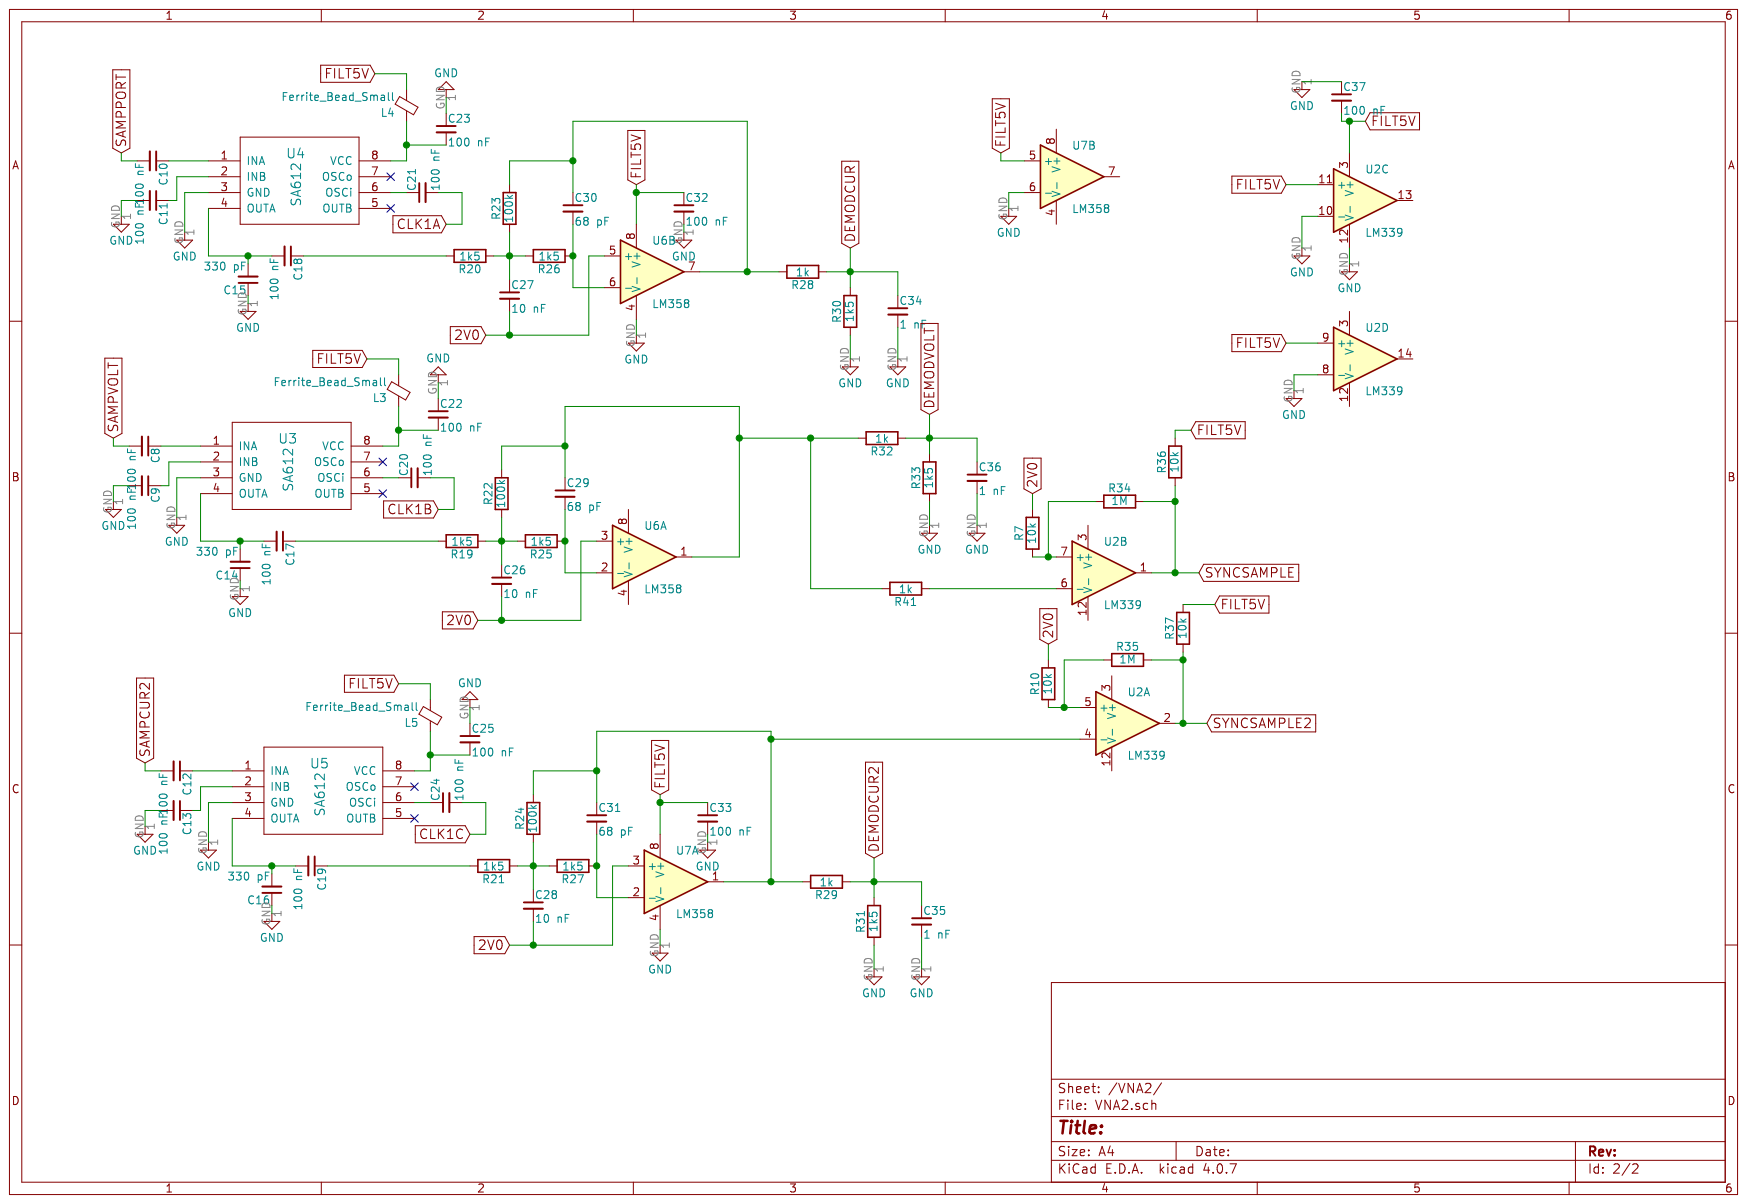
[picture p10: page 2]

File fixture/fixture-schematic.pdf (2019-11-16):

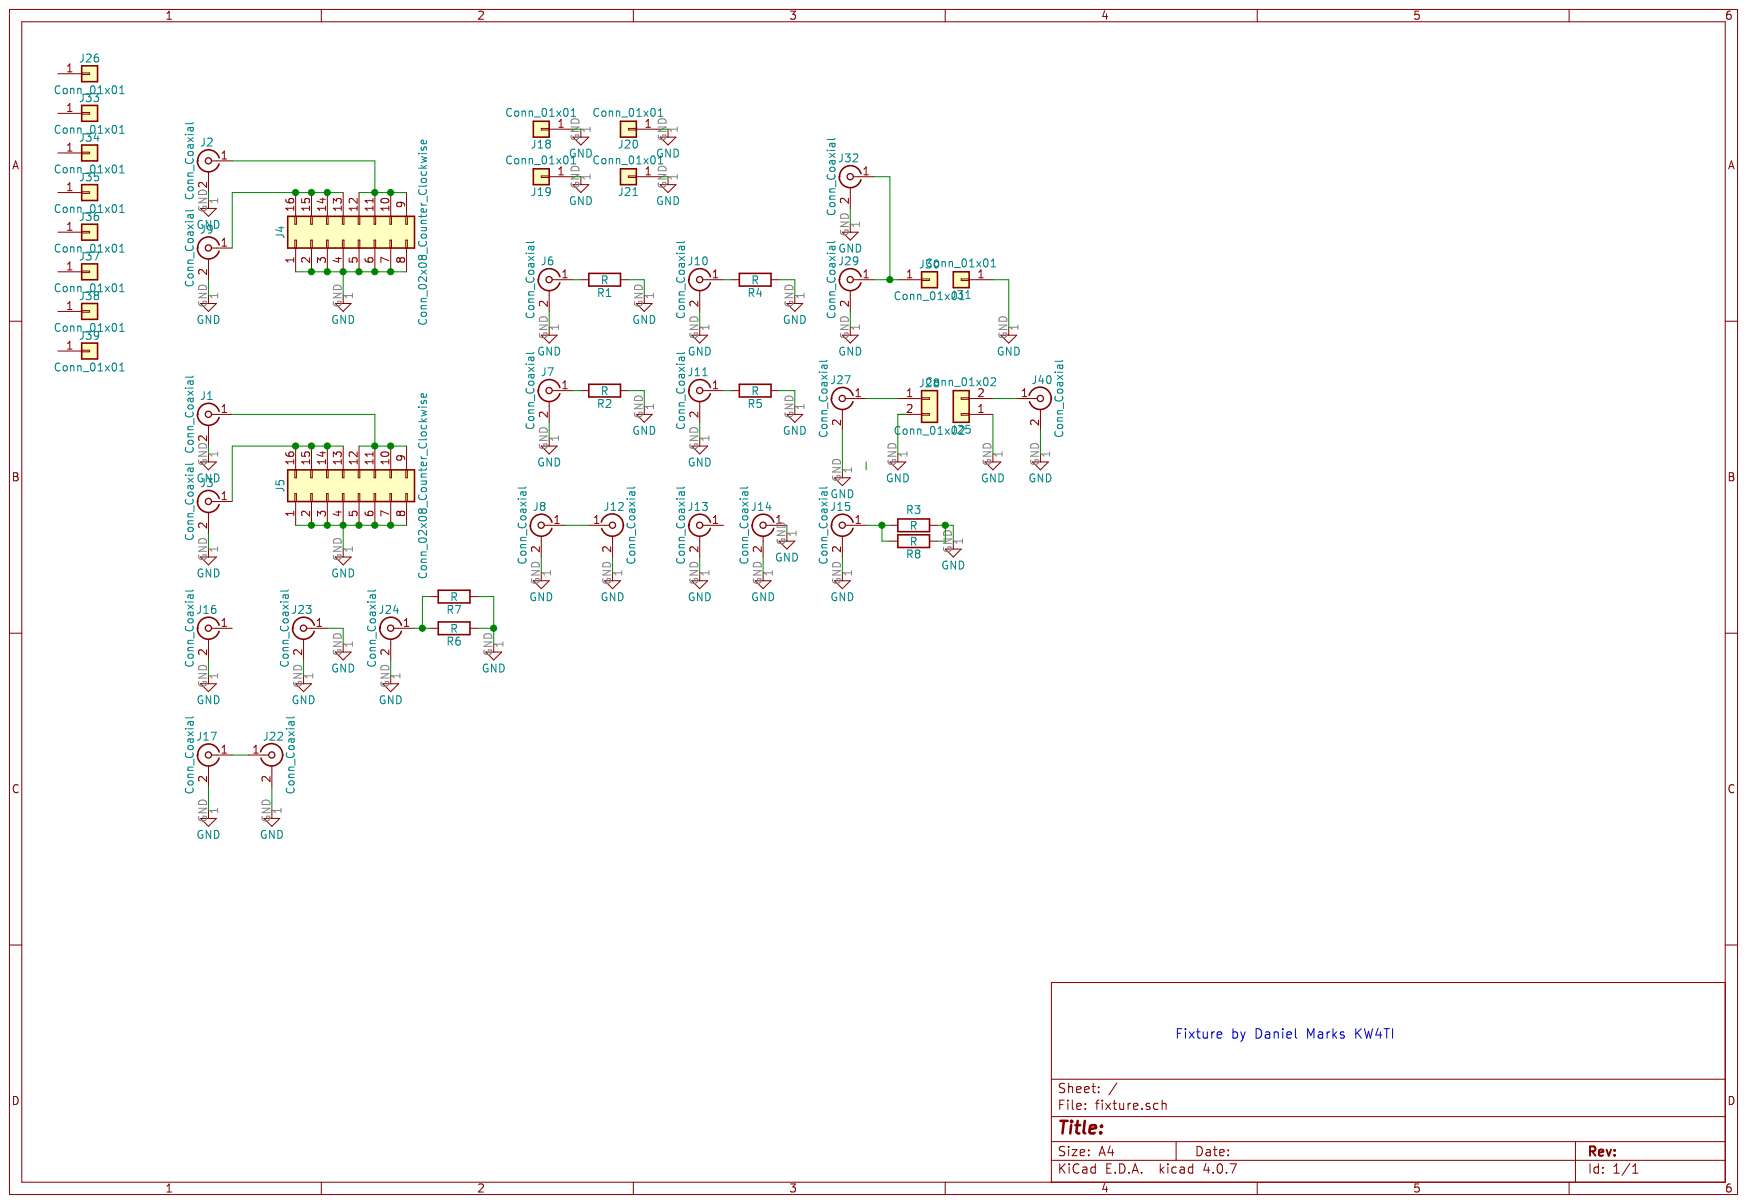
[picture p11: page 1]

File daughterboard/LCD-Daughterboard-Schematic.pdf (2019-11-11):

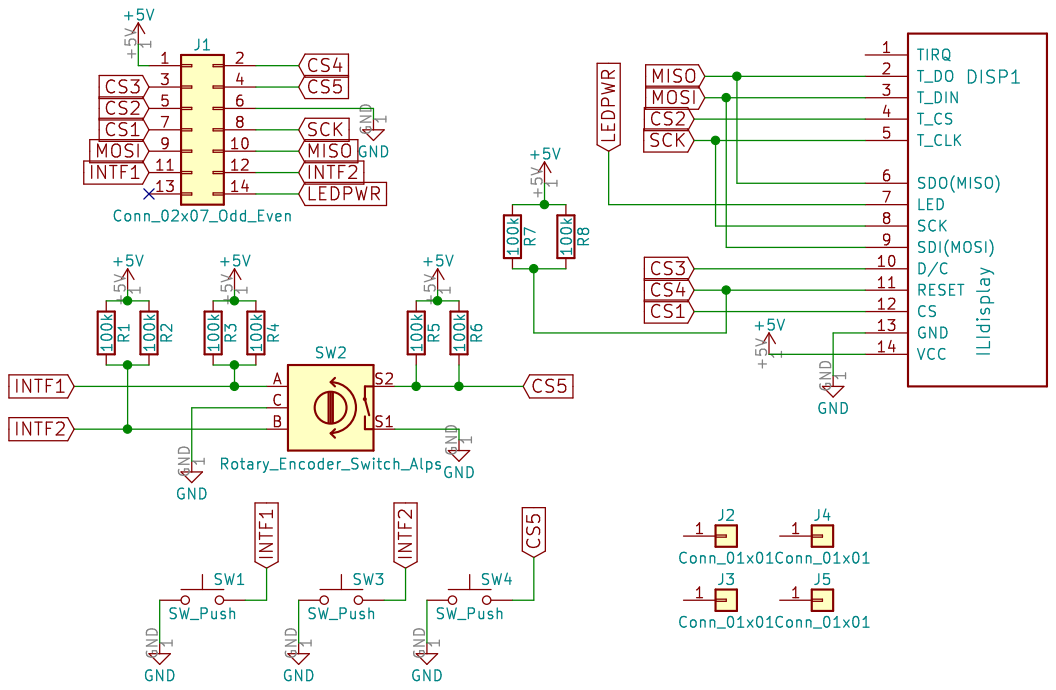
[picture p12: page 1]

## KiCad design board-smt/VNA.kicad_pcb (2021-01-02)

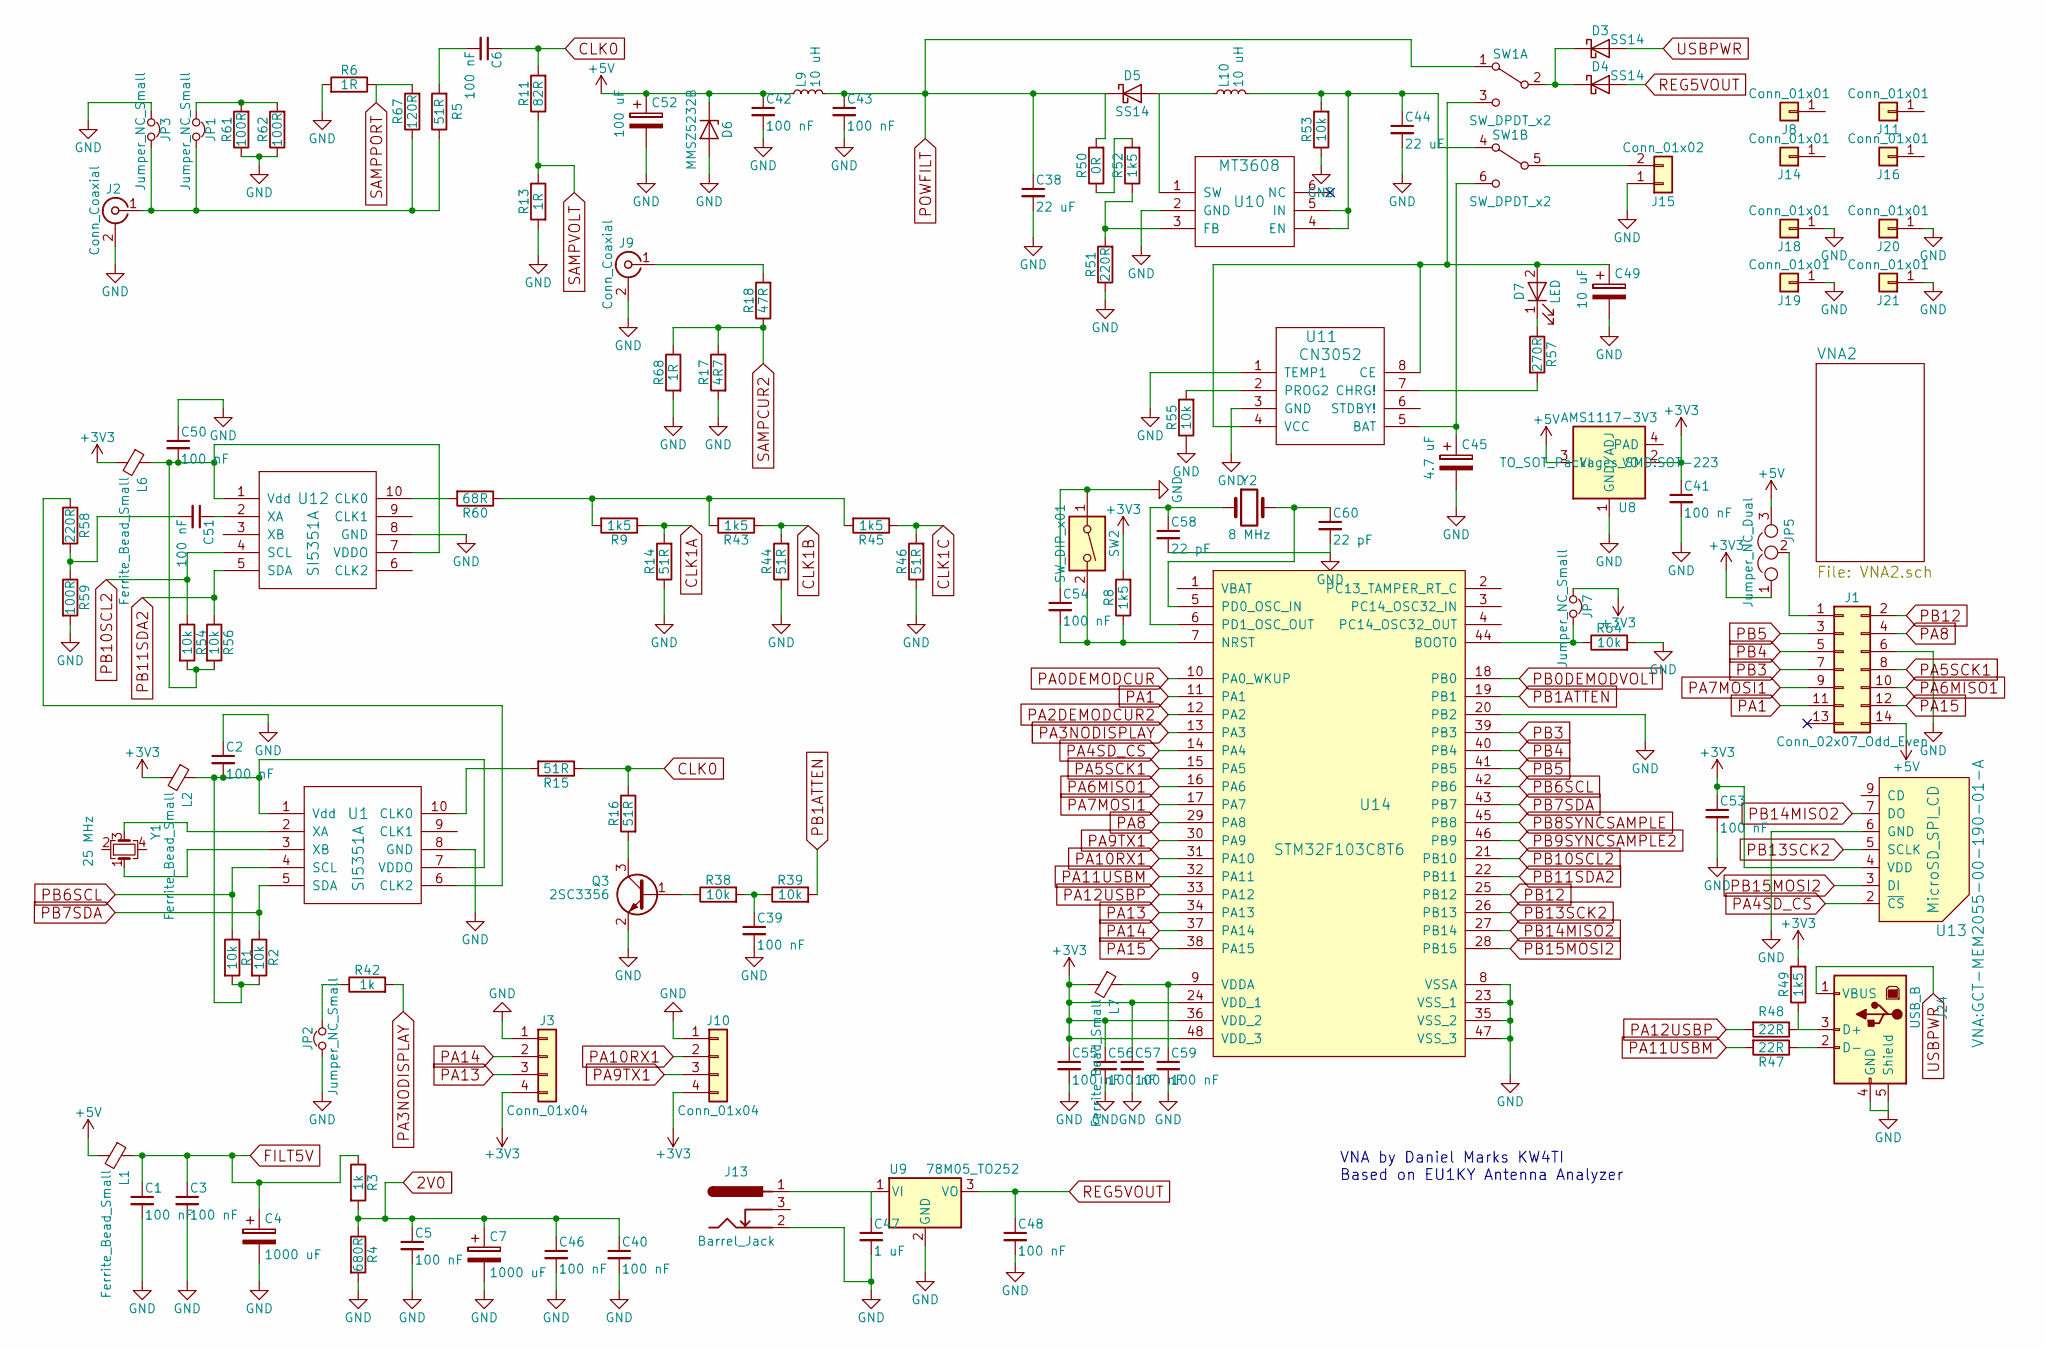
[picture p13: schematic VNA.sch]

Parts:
C1, C2, C3, C5, C6, C39, C40, C41, C42, C43, C46, C48, C50, C54, C55, C56, C57, C59: 100 nF; C_0805_HandSoldering; LCSC C49678
C4, C7: 1000 uF; CP_Elec_8x10.5
C38, C44: 22 uF; C_1210_HandSoldering
C45: 4.7 uF; CP_Elec_4x4.5
C47: 1 uF; C_0805_HandSoldering; LCSC C28323
C49: 10 uF; CP_Elec_4x4.5
C51, C53: 100 nF; C_0805_HandSoldering
C52: 100 uF; CP_Elec_4x4.5
C58, C60: 22 pF; C_0805_HandSoldering; LCSC C1804
D3, D4, D5: SS14; D_SMA; LCSC C2480
D6: MMSZ5232B; D_MiniMELF; LCSC C8062
D7: LED; LED_0805; LCSC C84256
J1: Conn_02x07_Odd_Even; Pin_Header_Straight_2x07_Pitch2.54mm
J2, J9: Conn_Coaxial; Amphenol_RF_SMA_132289
J3, J10: Conn_01x04; Pin_Header_Straight_1x04_Pitch2.54mm
J8, J11, J14, J16, J18, J19, J20, J21: Conn_01x01; 1pin
J13: Barrel_Jack; BARREL_JACK
J15: Conn_01x02; Molex_KK-6410-02_02x2.54mm_Straight
J24: USB_B
JP1, JP2, JP3, JP7: Jumper_NC_Small; Pin_Header_Straight_1x02_Pitch2.54mm
JP5: Jumper_NC_Dual; Pin_Header_Straight_1x03_Pitch2.54mm
L1, L2, L6, L7: Ferrite_Bead_Small; L_0805_HandSoldering; LCSC C1015
L9, L10: 10 uH; L_7.3x7.3_H4.5
Q3: 2SC3356; SOT-23; LCSC C9659
R1, R2, R38, R39, R53, R54, R55, R56, R64: 10k; R_0805_HandSoldering; LCSC C17414
R3, R42: 1k; R_0805_HandSoldering; LCSC C17513
R4: 680R; R_0805_HandSoldering; LCSC C17798
R5, R14, R15, R16, R44, R46: 51R; R_0805_HandSoldering; LCSC C17738
R6, R13, R68: 1R; R_0805_HandSoldering; LCSC C25271
R8, R9, R43, R45, R49, R52: 1k5; R_0805_HandSoldering; LCSC C4310
R11: 82R; R_0805_HandSoldering; LCSC C17841
R17: 4R7; R_0805_HandSoldering; LCSC C17675
R18: 47R; R_0805_HandSoldering; LCSC C17714
R47, R48: 22R; R_0805_HandSoldering; LCSC C17561
R50: 0R; R_0805_HandSoldering; LCSC C17477
R51, R58: 220R; R_0805_HandSoldering; LCSC C17557
R57: 270R; R_0805_HandSoldering; LCSC C17590
R59, R61, R62: 100R; R_0805_HandSoldering; LCSC C17408
R60: 68R; R_0805_HandSoldering; LCSC C17802
R67: 120R; R_0805_HandSoldering; LCSC C17437
SW1: SW_DPDT_x2; Molex_KK-6410-06_06x2.54mm_Straight
SW2: SW_DIP_x01; SW_PUSH_6mm
U1, U12: SI5351A; MSOP-10_3x3mm_Pitch0.5mm
U8: AMS1117-3V3; SOT-223; MPN LM1117; LCSC C6186
U9: 78M05_TO252; TO-252-3_TabPin2; LCSC C58069
U10: MT3608; SOT-23-6
U11: CN3052; TI_SO-PowerPAD-8
U13: MicroSD_SPI_CD; GCT-MEM2055-00-190-01-A
U14: STM32F103C8T6; LQFP-48_7x7mm_Pitch0.5mm; LCSC C8304
Y1: 25 MHz; Crystal_SMD_3225-4pin_3.2x2.5mm_HandSoldering; LCSC C9006
Y2: 8 MHz; Crystal_SMD_5032-2pin_5.0x3.2mm_HandSoldering; LCSC C115962

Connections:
2V0: C5.1, C7.1, C40.1, C46.1, R3.2, R4.1; also elsewhere on the board
+3V3: C41.1, C53.1, C55.1, C56.1, C57.1, J3.4, J10.4, JP5.1, JP7.1, L2.2, L6.2, L7.2, R8.2, R49.2, U8.2 (VO), U13.4 (VDD), U14.24 (VDD_1), U14.36 (VDD_2), U14.48 (VDD_3)
+5V: C42.1, C52.1, D6.1 (K), J1.14, JP5.3, L1.2, L9.1, U8.3 (VI)
CLK0: C6.1, R11.2, R15.1, R16.1
CLK1A: R9.1, R14.2; also elsewhere on the board
CLK1B: R43.1, R44.2; also elsewhere on the board
CLK1C: R45.1, R46.2; also elsewhere on the board
FILT5V: C1.1, C3.1, C4.1, L1.1, R3.1; also elsewhere on the board
GND: C1.2, C2.1, C3.2, C4.2, C5.2, C7.2, C38.2, C39.2, C40.2, C41.2, C42.2, C43.2, C44.2, C45.2, C46.2, C47.2, C48.2, C49.2, C50.1, C52.2, C53.2, C54.1, C55.2, C56.2, C57.2, C58.2, C59.2, C60.2, D6.2 (A), J1.6, J2.2 (Ext), J3.1, J9.2 (Ext), J10.1, J13.2, J15.1, J18.1, J19.1, J20.1, J21.1, J24.4 (GND), J24.5 (Shield), JP2.1, JP3.1, Q3.2 (E), R4.2, R6.2, R13.2, R14.1, R17.2, R44.1, R46.1, R51.1, R53.1, R55.1, R59.2, R61.1, R62.1, R64.2, R68.2, SW2.1, U1.8 (GND), U8.1 (GND/ADJ), U9.2 (GND), U10.2 (GND), U11.1 (TEMP1), U11.3 (GND), U12.8 (GND), U13.6 (GND), U14.8 (VSSA), U14.20 (PB2), U14.23 (VSS_1), U14.35 (VSS_2), U14.47 (VSS_3); also elsewhere on the board
unnamed: C2.2, L2.1, R1.2, R2.2, U1.1 (Vdd), U1.7 (VDDO)
unnamed: C6.2, R5.2
unnamed: C39.1, R38.2, R39.1
unnamed: C44.1, L10.2, R53.2, SW1.4 (A), U10.4 (EN), U10.5 (IN)
unnamed: C45.1, SW1.6 (C), U11.5 (BAT)
unnamed: C47.1, J13.1, U9.1 (VI)
unnamed: C49.1, D7.2 (A), SW1.3 (C), U11.4 (VCC), U11.8 (CE)
unnamed: C50.2, L6.1, R54.2, R56.2, U12.1 (Vdd), U12.7 (VDDO)
unnamed: C51.1, U12.2 (XA)
unnamed: C51.2, R58.2, R59.1
unnamed: C54.2, R8.1, SW2.2, U14.7 (NRST)
unnamed: C58.1, U14.6 (PD1_OSC_OUT), Y2.1
unnamed: C59.1, L7.1, U14.9 (VDDA)
unnamed: C60.1, U14.5 (PD0_OSC_IN), Y2.2
unnamed: D3.1 (K), D4.1 (K), SW1.2 (B)
unnamed: D5.2 (A), L10.1, U10.1 (SW)
unnamed: D7.1 (K), R57.1
unnamed: J1.1, JP5.2
unnamed: J2.1 (In), JP1.2, JP3.2, R5.1, R67.1
unnamed: J9.1 (In), R18.2
unnamed: J15.2, SW1.5 (B)
unnamed: J24.2 (D-), R47.1
unnamed: J24.3 (D+), R48.1, R49.1
unnamed: JP1.1, R61.2, R62.2
unnamed: JP2.2, R42.1
unnamed: JP7.2, R64.1, U14.44 (BOOT0)
unnamed: Q3.1 (B), R38.1
unnamed: Q3.3 (C), R16.2
unnamed: R15.2, U1.10 (CLK0)
unnamed: R9.2, R43.2, R45.2, R60.1
unnamed: R50.1, R52.2
unnamed: R51.2, R52.1, U10.3 (FB)
unnamed: R55.2, U11.2 (PROG2)
unnamed: R57.2, U11.7 (CHRG!)
unnamed: R58.1, U1.6 (CLK2)
unnamed: R60.2, U12.10 (CLK0)
unnamed: U1.2 (XA), Y1.3
unnamed: U1.3 (XB), Y1.1
PA0DEMODCUR: U14.10 (PA0_WKUP); also elsewhere on the board
PA1: J1.11, U14.11 (PA1)
PA2DEMODCUR2: U14.12 (PA2); also elsewhere on the board
PA3NODISPLAY: R42.2, U14.13 (PA3)
PA4SD_CS: U13.2 (~CS), U14.14 (PA4)
PA5SCK1: J1.8, U14.15 (PA5)
PA6MISO1: J1.10, U14.16 (PA6)
PA7MOSI1: J1.9, U14.17 (PA7)
PA8: J1.4, U14.29 (PA8)
PA9TX1: J10.3, U14.30 (PA9)
PA10RX1: J10.2, U14.31 (PA10)
PA11USBM: R47.2, U14.32 (PA11)
PA12USBP: R48.2, U14.33 (PA12)
PA13: J3.3, U14.34 (PA13)
PA14: J3.2, U14.37 (PA14)
PA15: J1.12, U14.38 (PA15)
PB0DEMODVOLT: U14.18 (PB0); also elsewhere on the board
PB1ATTEN: R39.2, U14.19 (PB1)
PB3: J1.7, U14.39 (PB3)
PB4: J1.5, U14.40 (PB4)
PB5: J1.3, U14.41 (PB5)
PB6SCL: R1.1, U1.4 (SCL), U14.42 (PB6)
PB7SDA: R2.1, U1.5 (SDA), U14.43 (PB7)
PB8SYNCSAMPLE: U14.45 (PB8); also elsewhere on the board
PB9SYNCSAMPLE2: U14.46 (PB9); also elsewhere on the board
PB10SCL2: R54.1, U12.4 (SCL), U14.21 (PB10)
PB11SDA2: R56.1, U12.5 (SDA), U14.22 (PB11)
PB12: J1.2, U14.25 (PB12)
PB13SCK2: U13.5 (SCLK), U14.26 (PB13)
PB14MISO2: U13.7 (DO), U14.27 (PB14)
PB15MOSI2: U13.3 (DI), U14.28 (PB15)
POWFILT: C38.1, C43.1, D5.1 (K), L9.2, R50.2, SW1.1 (A)
REG5VOUT: C48.1, D4.2 (A), U9.3 (VO)
SAMPCUR2: R17.1, R18.1, R68.1; also elsewhere on the board
SAMPPORT: R6.1, R67.2; also elsewhere on the board
SAMPVOLT: R11.1, R13.1; also elsewhere on the board
USBPWR: D3.2 (A), J24.1 (VBUS)

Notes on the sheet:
VNA by Daniel Marks KW4TI Based on EU1KY Antenna Analyzer

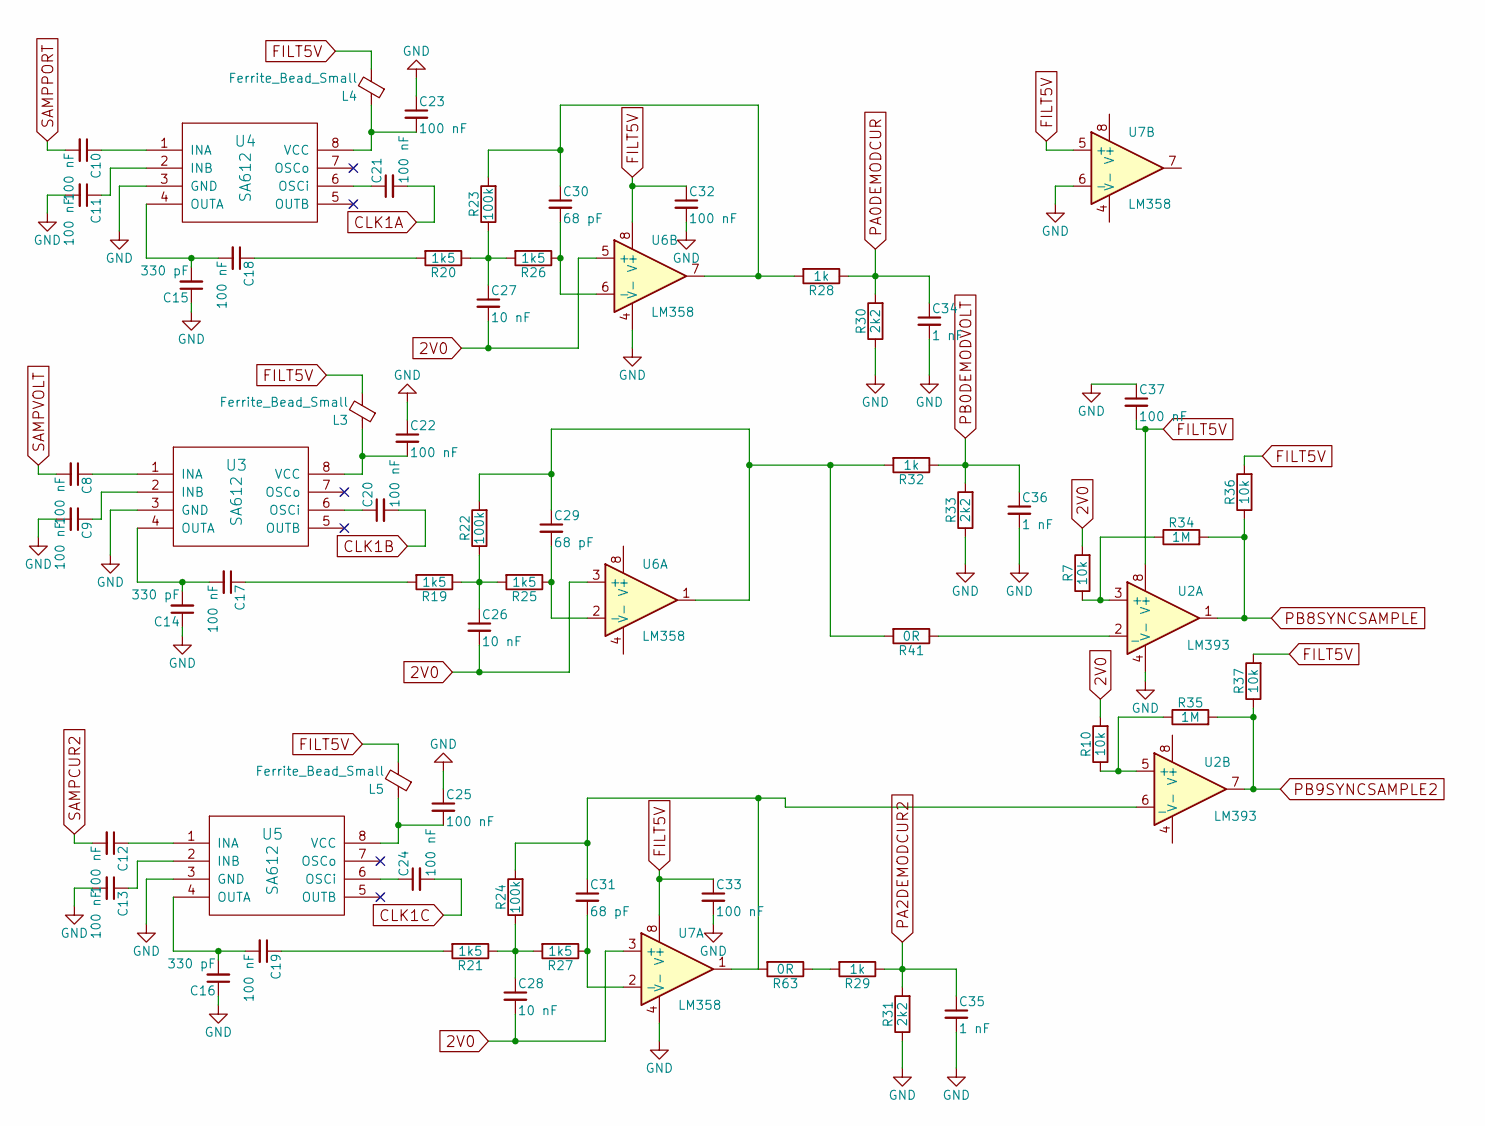
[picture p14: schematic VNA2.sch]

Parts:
C8, C9, C10, C11, C12, C13, C17, C18, C19, C20, C21, C22, C23, C24, C32, C33: 100 nF; C_0805_HandSoldering; LCSC C49678
C14, C15, C16: 330 pF; C_0805_HandSoldering; LCSC C51207
C25, C37: 100 nF; C_0805_HandSoldering
C26, C27, C28: 10 nF; C_0805_HandSoldering; LCSC C1710
C29, C30, C31: 68 pF; C_0805_HandSoldering; LCSC C1834
C34, C35, C36: 1 nF; C_0805_HandSoldering; LCSC C46653
L3, L4, L5: Ferrite_Bead_Small; L_0805_HandSoldering; LCSC C1015
R7, R10, R36, R37: 10k; R_0805_HandSoldering; LCSC C17414
R19, R20, R21, R25, R26, R27: 1k5; R_0805_HandSoldering; LCSC C4310
R22, R23, R24: 100k; R_0805_HandSoldering; LCSC C17407
R28, R29, R32: 1k; R_0805_HandSoldering; LCSC C17513
R30, R31, R33: 2k2; R_0805_HandSoldering; LCSC C17520
R34, R35: 1M; R_0805_HandSoldering; LCSC C17514
R41, R63: 0R; R_0805_HandSoldering; LCSC C17477
U2: LM393; SOIC-8_3.9x4.9mm_Pitch1.27mm; LCSC C7955
U3, U4, U5: SA612; SOIC-8_3.9x4.9mm_Pitch1.27mm
U6, U7: LM358; SOIC-8_3.9x4.9mm_Pitch1.27mm; LCSC C7950

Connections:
2V0: C26.2, C27.2, C28.2, R7.2, R10.2, U6.3 (+), U6.5 (+), U7.3 (+); also elsewhere on the board
CLK1A: C21.2; also elsewhere on the board
CLK1B: C20.2; also elsewhere on the board
CLK1C: C24.2; also elsewhere on the board
FILT5V: C32.1, C33.1, C37.2, L3.2, L4.2, L5.2, R36.2, R37.2, U2.8 (V+), U6.8 (V+), U7.5 (+), U7.8 (V+); also elsewhere on the board
GND: C9.2, C11.2, C13.2, C14.1, C15.1, C16.1, C22.1, C23.1, C25.1, C32.2, C33.2, C34.2, C35.2, C36.2, C37.1, R30.1, R31.1, R33.1, U2.4 (V-), U3.3 (GND), U4.3 (GND), U5.3 (GND), U6.4 (V-), U7.4 (V-), U7.6 (-); also elsewhere on the board
unnamed: C8.1, U3.1 (INA)
unnamed: C9.1, U3.2 (INB)
unnamed: C10.1, U4.1 (INA)
unnamed: C11.1, U4.2 (INB)
unnamed: C12.1, U5.1 (INA)
unnamed: C13.1, U5.2 (INB)
unnamed: C14.2, C17.2, U3.4 (OUTA)
unnamed: C15.2, C18.2, U4.4 (OUTA)
unnamed: C16.2, C19.2, U5.4 (OUTA)
unnamed: C17.1, R19.2
unnamed: C18.1, R20.2
unnamed: C19.1, R21.2
unnamed: C20.1, U3.6 (OSCi)
unnamed: C21.1, U4.6 (OSCi)
unnamed: C22.2, L3.1, U3.8 (VCC)
unnamed: C23.2, L4.1, U4.8 (VCC)
unnamed: C24.1, U5.6 (OSCi)
unnamed: C25.2, L5.1, U5.8 (VCC)
unnamed: C26.1, R19.1, R22.1, R25.2
unnamed: C27.1, R20.1, R23.1, R26.2
unnamed: C28.1, R21.1, R24.1, R27.2
unnamed: C29.1, R22.2, R32.2, R41.2, U6.1
unnamed: C29.2, R25.1, U6.2 (-)
unnamed: C30.1, R23.2, R28.2, U6.7
unnamed: C30.2, R26.1, U6.6 (-)
unnamed: C31.1, R24.2, R63.2, U2.6 (_), U7.1
unnamed: C31.2, R27.1, U7.2 (-)
unnamed: R10.1, R35.1, U2.5 (+)
unnamed: R29.2, R63.1
unnamed: R7.1, R34.1, U2.3 (+)
unnamed: R41.1, U2.2 (_)
PA0DEMODCUR: C34.1, R28.1, R30.2; also elsewhere on the board
PA2DEMODCUR2: C35.1, R29.1, R31.2; also elsewhere on the board
PB0DEMODVOLT: C36.1, R32.1, R33.2; also elsewhere on the board
PB8SYNCSAMPLE: R34.2, R36.1, U2.1; also elsewhere on the board
PB9SYNCSAMPLE2: R35.2, R37.1, U2.7; also elsewhere on the board
SAMPCUR2: C12.2; also elsewhere on the board
SAMPPORT: C10.2; also elsewhere on the board
SAMPVOLT: C8.2; also elsewhere on the board

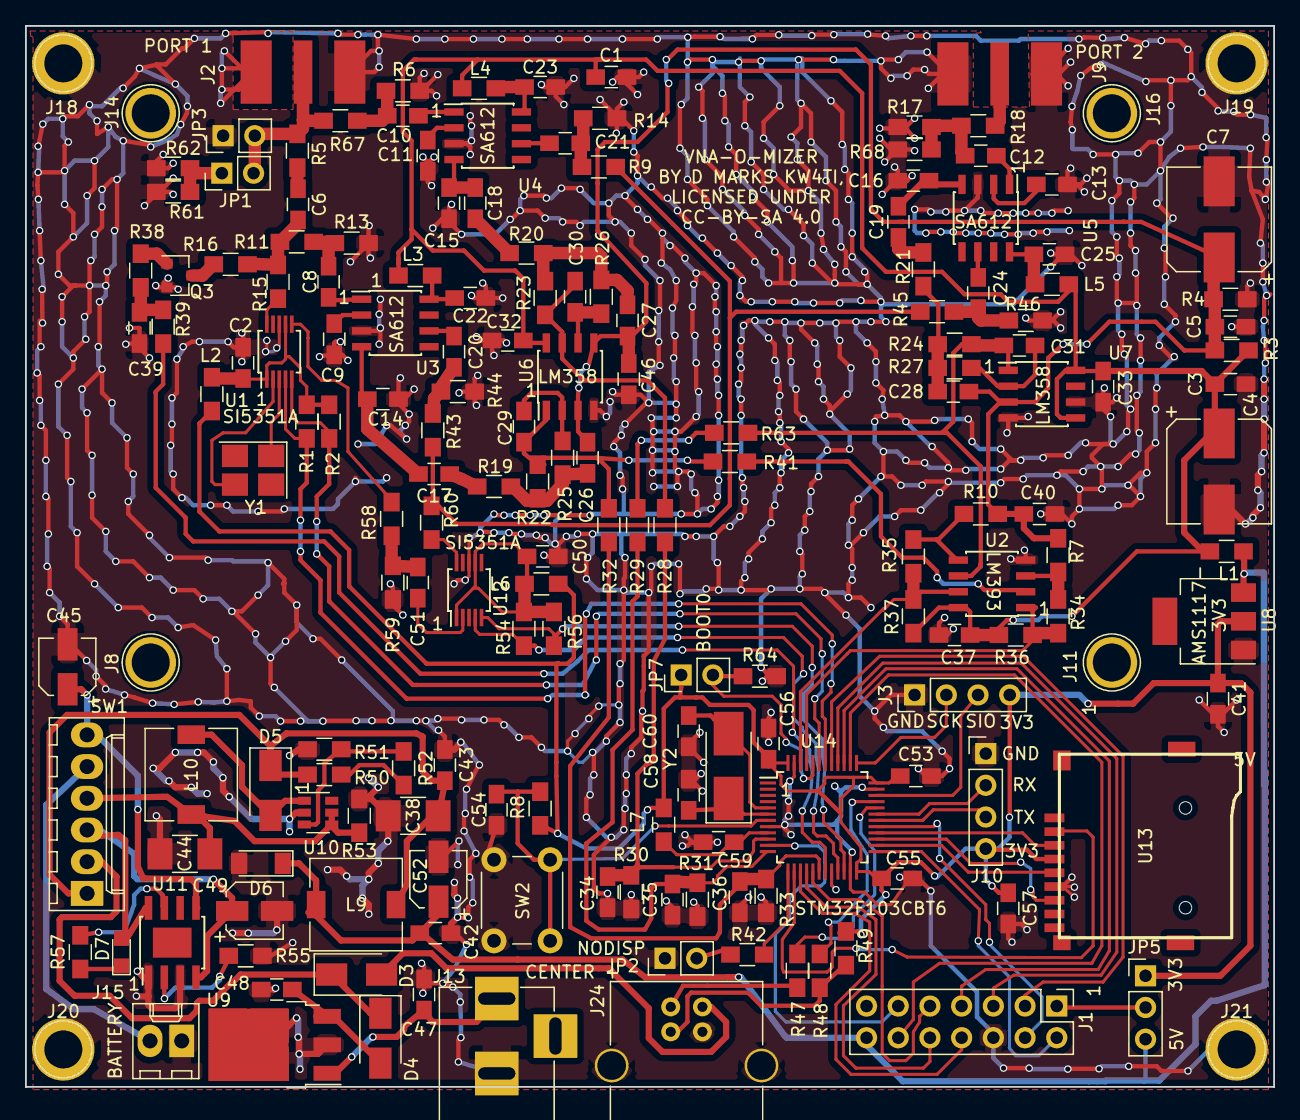
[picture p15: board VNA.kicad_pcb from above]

Board: 2 copper layers, 100.0 x 85.0 mm, 178 parts (0 on the bottom side), 115 nets.

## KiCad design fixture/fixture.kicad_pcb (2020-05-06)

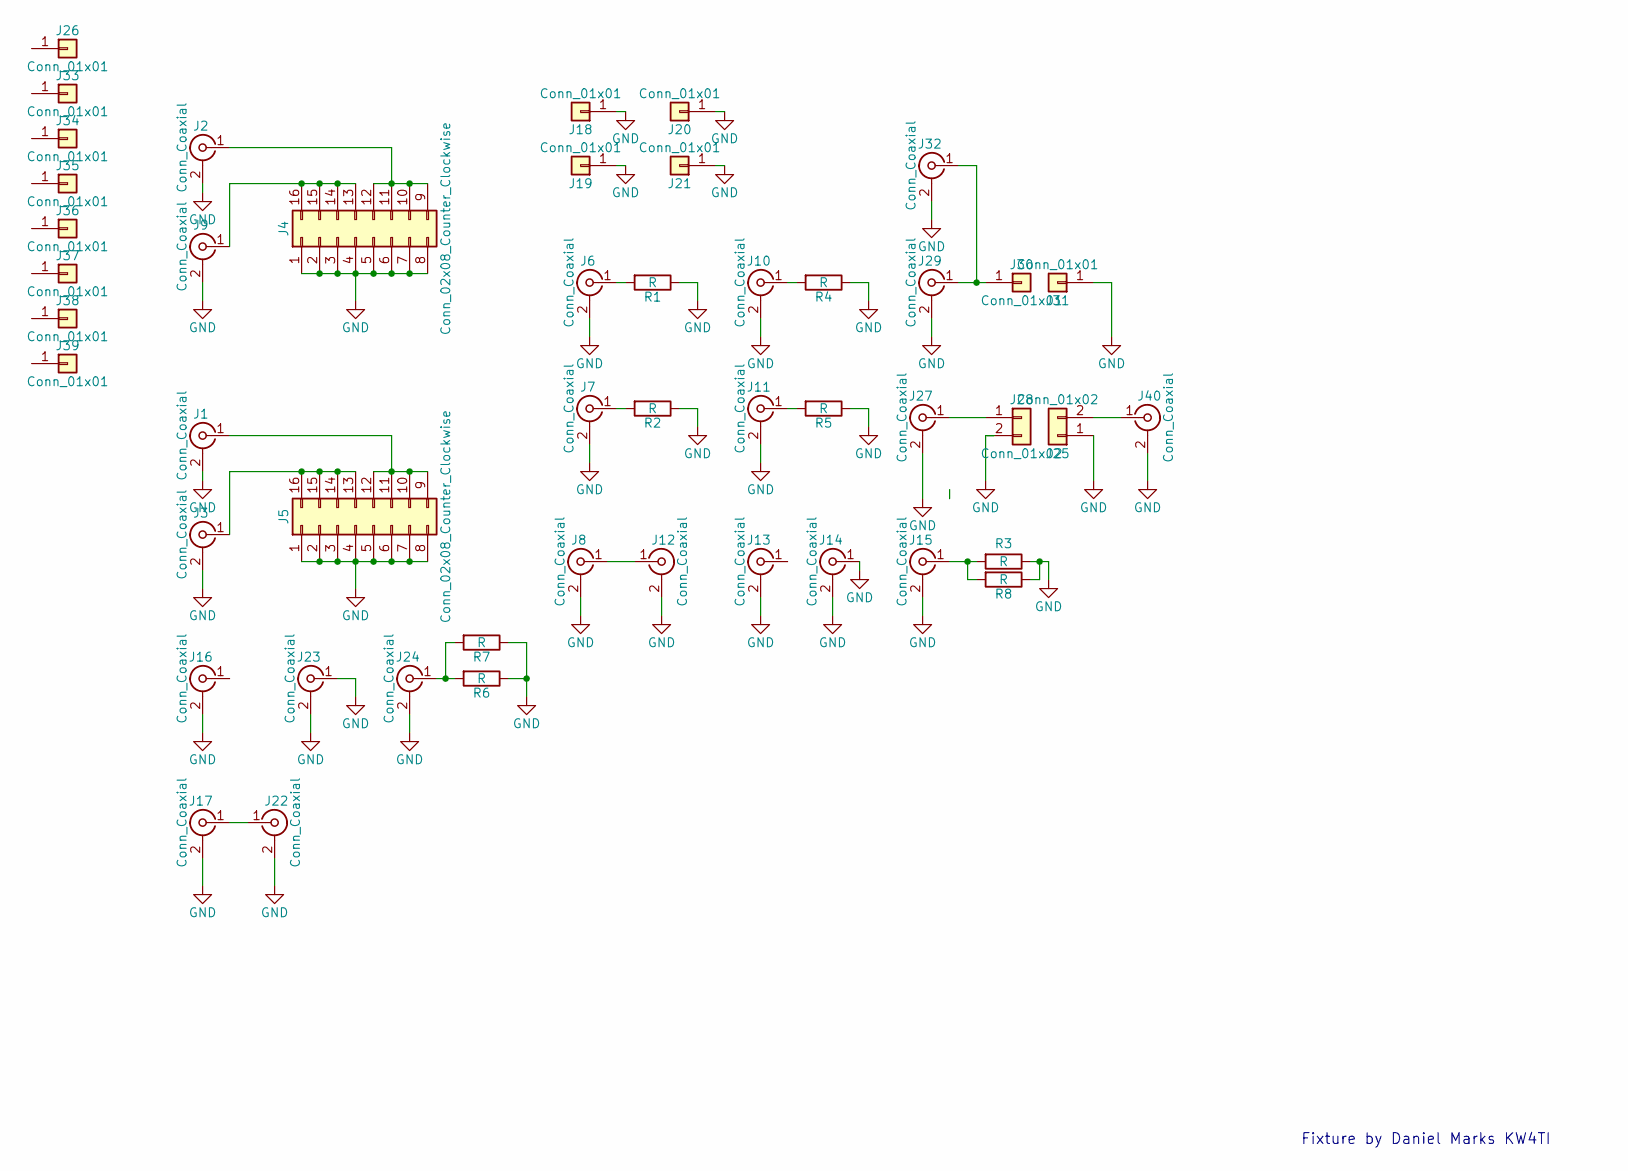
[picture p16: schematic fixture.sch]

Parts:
J1, J3, J16, J17, J22, J23, J24, J32: Conn_Coaxial; bnc-ci
J2, J6, J7, J8, J9, J10, J11, J12, J13, J14, J15, J27, J29, J40: Conn_Coaxial; Amphenol_RF_SMA_132289
J4, J5: Conn_02x08_Counter_Clockwise; ZIFSocket16pin
J18, J19, J20, J21, J30, J31: Conn_01x01; 1pin
J25, J28: Conn_01x02; TerminalBlock_bornier-2_P5.08mm
J26, J33, J34, J35, J36, J37, J38, J39: Conn_01x01; AirHole
R1, R2, R3, R4, R5, R6, R7, R8: R; R_0805_HandSoldering

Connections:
GND: J1.2 (Ext), J2.2 (Ext), J3.2 (Ext), J4.1, J4.2, J4.3, J4.4, J4.5, J4.6, J4.7, J4.8, J5.1, J5.2, J5.3, J5.4, J5.5, J5.6, J5.7, J5.8, J6.2 (Ext), J7.2 (Ext), J8.2 (Ext), J9.2 (Ext), J10.2 (Ext), J11.2 (Ext), J12.2 (Ext), J13.2 (Ext), J14.1 (In), J14.2 (Ext), J15.2 (Ext), J16.2 (Ext), J17.2 (Ext), J18.1, J19.1, J20.1, J21.1, J22.2 (Ext), J23.1 (In), J23.2 (Ext), J24.2 (Ext), J25.1, J27.2 (Ext), J28.2, J29.2 (Ext), J31.1, J32.2 (Ext), J40.2 (Ext), R1.1, R2.1, R3.1, R4.1, R5.1, R6.1, R7.1, R8.1
unnamed: J1.1 (In), J5.9, J5.10, J5.11, J5.12
unnamed: J2.1 (In), J4.9, J4.10, J4.11, J4.12
unnamed: J3.1 (In), J5.13, J5.14, J5.15, J5.16
unnamed: J4.13, J4.14, J4.15, J4.16, J9.1 (In)
unnamed: J6.1 (In), R1.2
unnamed: J7.1 (In), R2.2
unnamed: J10.1 (In), R4.2
unnamed: J11.1 (In), R5.2
unnamed: J8.1 (In), J12.1 (In)
unnamed: J15.1 (In), R3.2, R8.2
unnamed: J17.1 (In), J22.1 (In)
unnamed: J24.1 (In), R6.2, R7.2
unnamed: J25.2, J40.1 (In)
unnamed: J27.1 (In), J28.1
unnamed: J29.1 (In), J30.1, J32.1 (In)

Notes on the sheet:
Fixture by Daniel Marks KW4TI

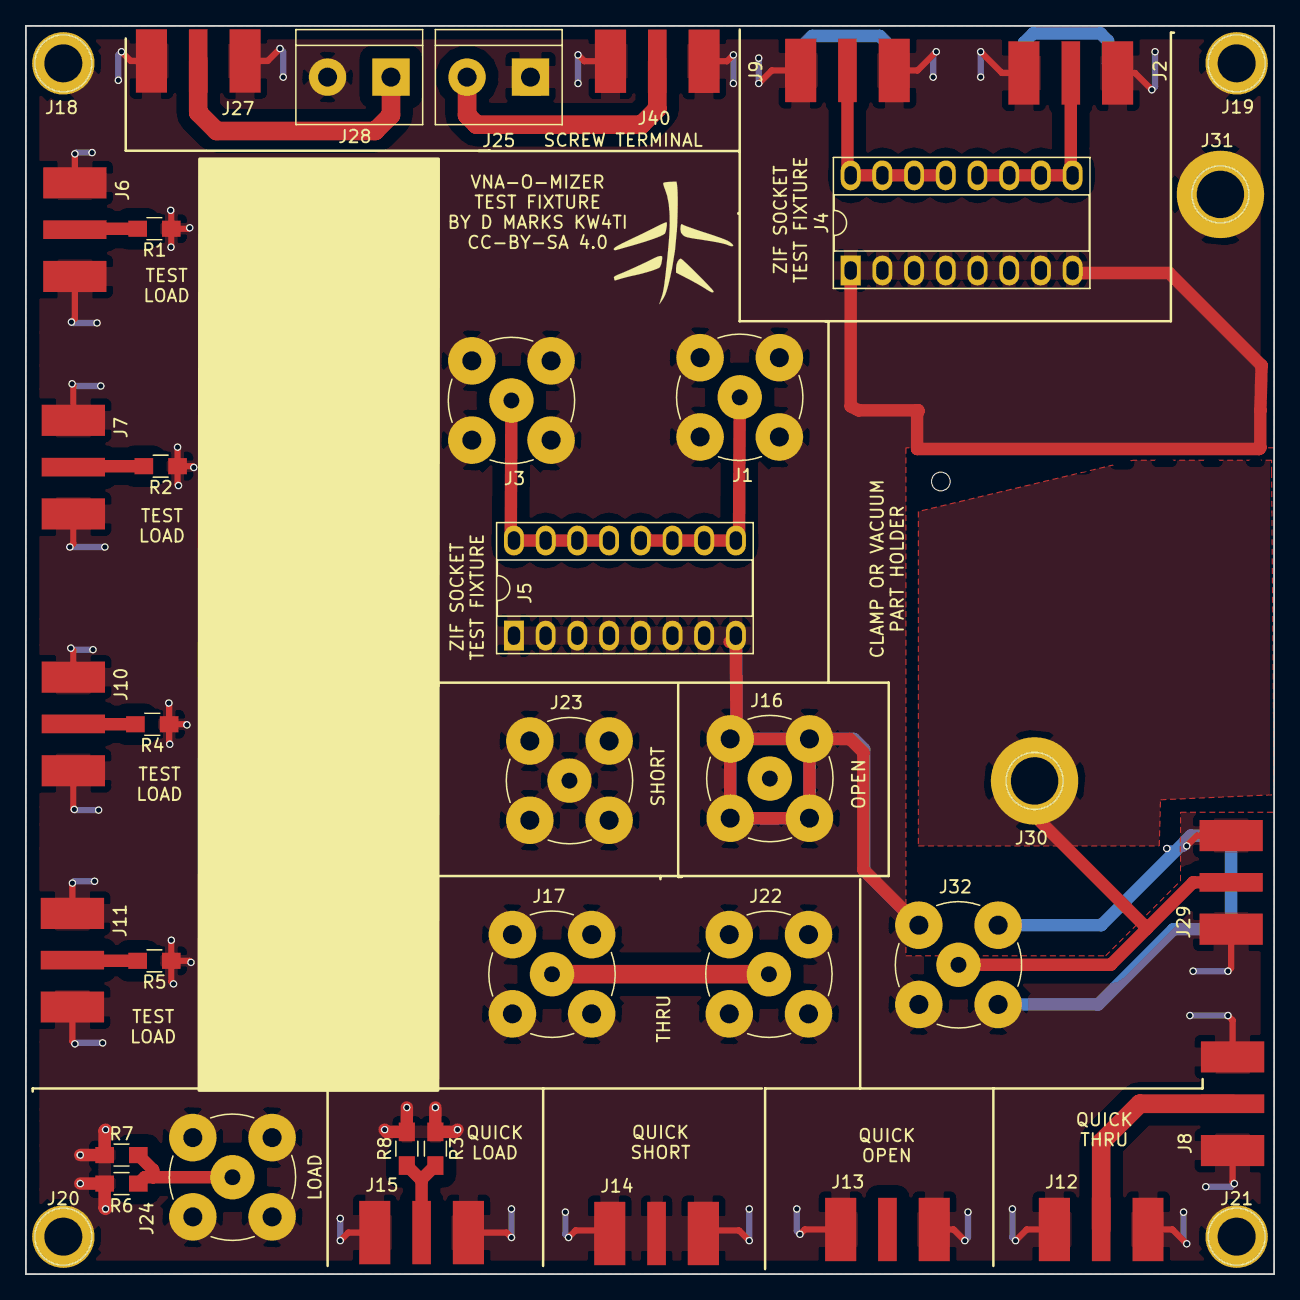
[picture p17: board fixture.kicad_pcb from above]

Board: 2 copper layers, 100.0 x 100.0 mm, 48 parts (0 on the bottom side), 16 nets.

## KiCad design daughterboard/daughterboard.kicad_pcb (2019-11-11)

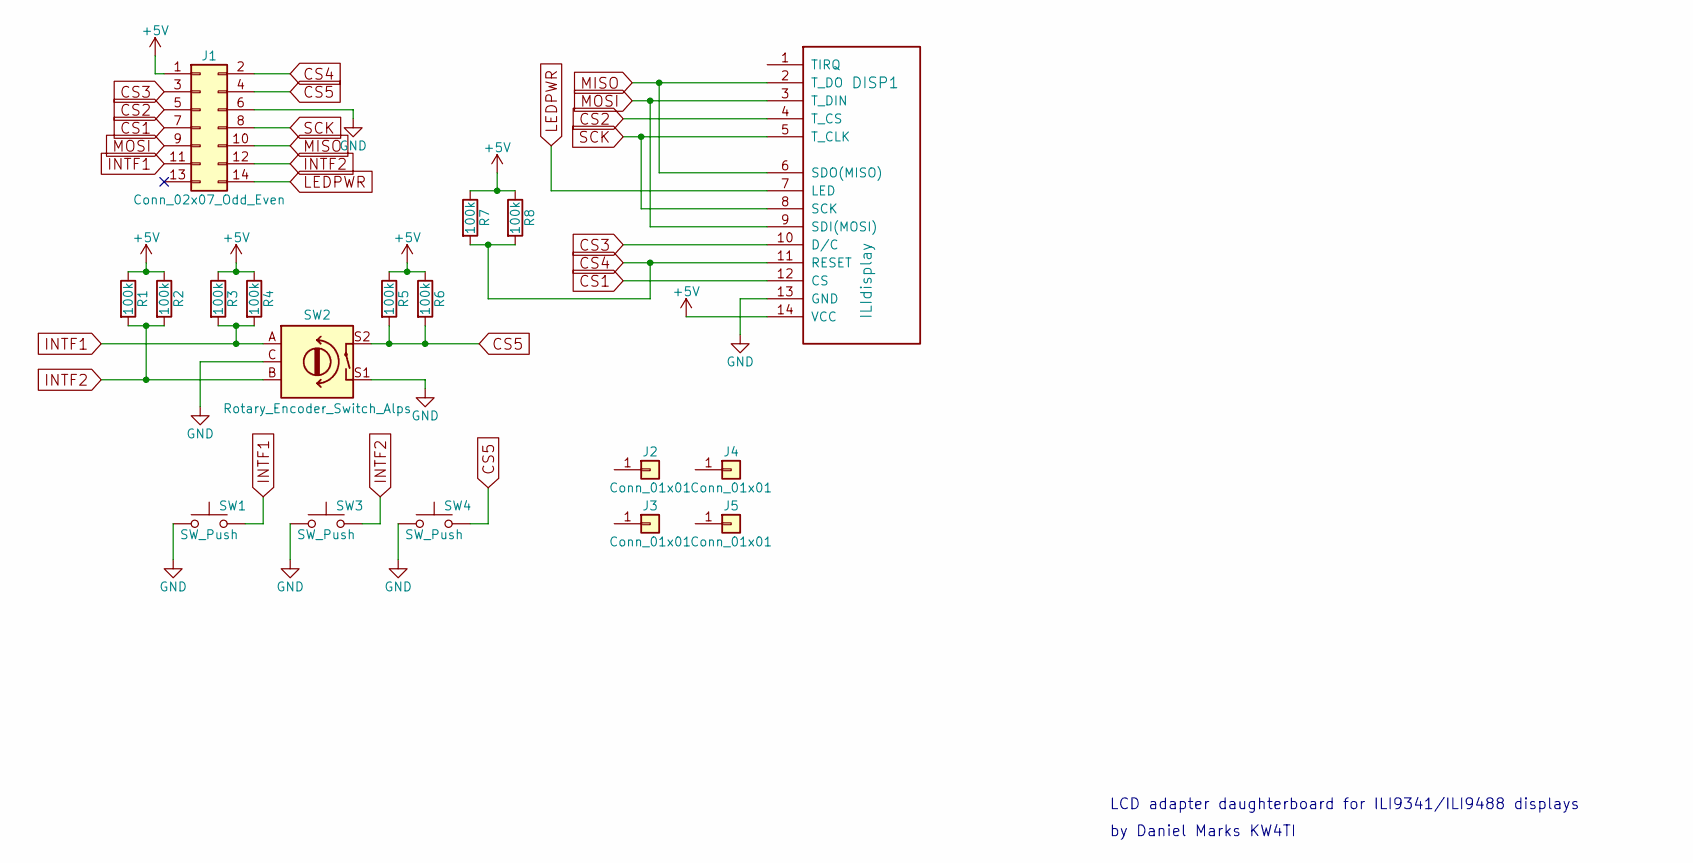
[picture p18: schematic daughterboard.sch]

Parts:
DISP1: ILIdisplay; Pin_Header_Straight_1x14_Pitch2.54mm
J1: Conn_02x07_Odd_Even; Pin_Header_Straight_2x07_Pitch2.54mm
J2, J3, J4, J5: Conn_01x01; 1pin
R1, R3, R5, R7: 100k; R_0805_HandSoldering
R2, R4, R6, R8: 100k; R_Axial_DIN0207_L6.3mm_D2.5mm_P7.62mm_Horizontal
SW1, SW3, SW4: SW_Push; SW_PUSH_6mm
SW2: Rotary_Encoder_Switch_Alps; RotaryEncoder_Alps_EC11E-Switch_Vertical_H20mm

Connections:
+5V: DISP1.14 (VCC), J1.1, R1.1, R2.1, R3.1, R4.1, R5.1, R6.1, R7.1, R8.1
CS1: DISP1.12 (CS), J1.7
CS2: DISP1.4 (T_CS), J1.5
CS3: DISP1.10 (D/C), J1.3
CS4: DISP1.11 (RESET), J1.2, R7.2, R8.2
CS5: J1.4, R5.2, R6.2, SW2.S2, SW4.2
GND: DISP1.13 (GND), J1.6, SW1.1, SW2.C, SW2.S1, SW3.1, SW4.1
INTF1: J1.11, R3.2, R4.2, SW1.2, SW2.A
INTF2: J1.12, R1.2, R2.2, SW2.B, SW3.2
LEDPWR: DISP1.7 (LED), J1.14
MISO: DISP1.2 (T_DO), DISP1.6 (SDO(MISO)), J1.10
MOSI: DISP1.3 (T_DIN), DISP1.9 (SDI(MOSI)), J1.9
SCK: DISP1.5 (T_CLK), DISP1.8 (SCK), J1.8

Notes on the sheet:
LCD adapter daughterboard for ILI9341/ILI9488 displays
by Daniel Marks KW4TI

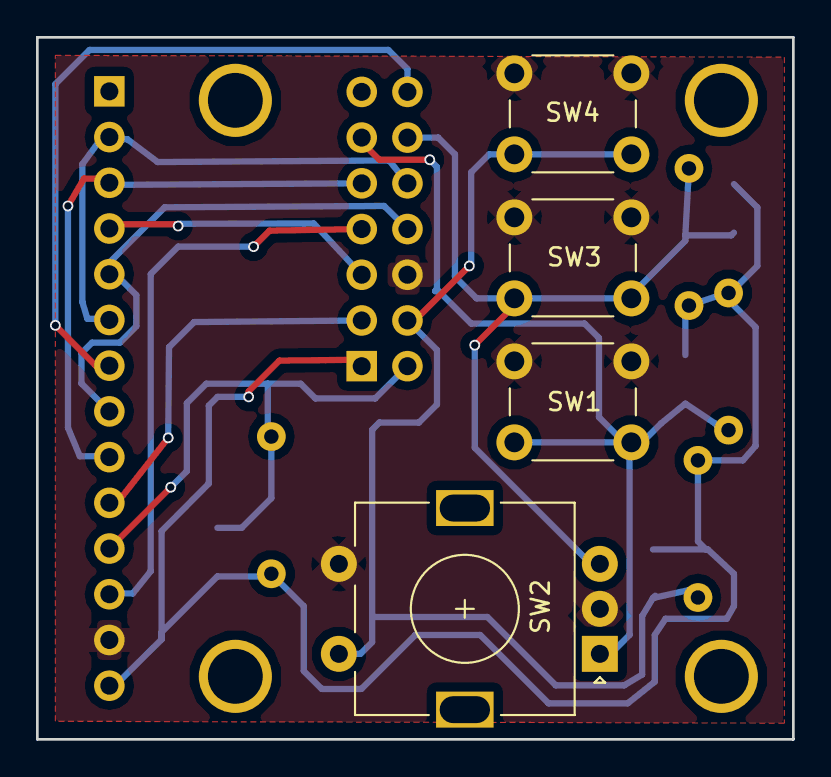
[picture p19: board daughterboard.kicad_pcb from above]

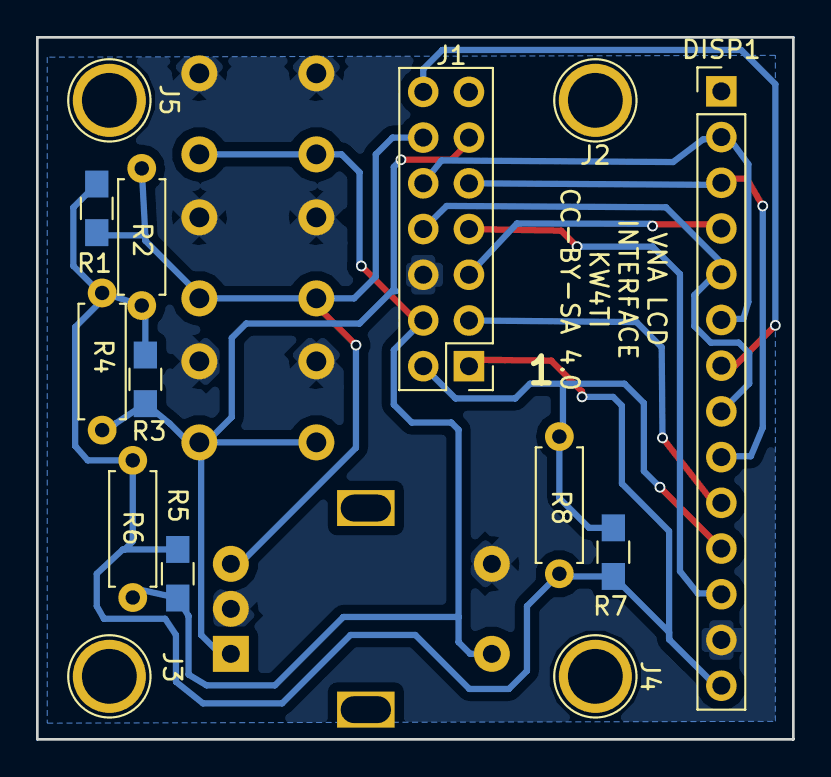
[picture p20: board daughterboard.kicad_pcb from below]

Board: 2 copper layers, 42.0 x 39.0 mm, 18 parts (14 on the bottom side), 13 nets.

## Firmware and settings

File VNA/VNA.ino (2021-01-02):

/* VNA

*/

/*
   Copyright (c) 2018 Daniel Marks

  This software is provided 'as-is', without any express or implied
  warranty. In no event will the authors be held liable for any damages
  arising from the use of this software.

  Permission is granted to anyone to use this software for any purpose,
  including commercial applications, and to alter it and redistribute it
  freely, subject to the following restrictions:

  1. The origin of this software must not be misrepresented; you must not
   claim that you wrote the original software. If you use this software
   in a product, an acknowledgment in the product documentation would be
   appreciated but is not required.
  2. Altered source versions must be plainly marked as such, and must not be
   misrepresented as being the original software.
  3. This notice may not be removed or altered from any source distribution.
*/

#include <Wire.h>
#include "VNA.h"
#include "si5351.h"
#include "tinycl.h"
#include "debugmsg.h"
#include "complex.h"
#include "flashstruct.h"
#include "mini-printf.h"
#include "consoleio.h"

#include <ff.h>

#ifdef VNA_TOUCHSCREEN
#include "touchscreen.h"
#endif

#define IFCLOCK_PIN PB8
#define IFCLOCK_PORT2_PIN PB9
#define AD_CUR_PIN PA0
#define AD_VOLT_PIN PB0
#define AD_CUR2_PIN PA2
#define ATTEN_PIN PB1
#define TOUCHSCREEN_DISABLE_PIN PA3

#ifdef VNA_TOUCHSCREEN
bool touchscreen_enabled;
#endif

#define PACETIMER TIMER2
#define PACETIMER_NVIC NVIC_TIMER2

Si5351 si5351(SI5351_BUS_BASE_ADDR,0);
Si5351 si5351b(SI5351_BUS_BASE_ADDR,1);

int pinMapADCCURPINin;
int pinMapADCVOLTPINin;
int pinMapADCCUR2PINin;

const vna_flash_header flash_header = { 0xDEADBEEF, 0xC001ACE5 };
vna_acquisition_state vna_state = {1000000u, 30000000u, 1000000u, 30000000u, 50u, 64, 1000, VNA_MAX_CAL_FREQS, VNA_MAX_ACQ_FREQS, 0, 0, 0, 0, VNA_NO_CALIB };
vna_calib_oneport *vna_1pt = NULL;
vna_calib_freq_parm vna_calib[VNA_MAX_CAL_FREQS];

void setup_analog(int accurate)
{
  pinMapADCCURPINin = PIN_MAP[AD_CUR_PIN].adc_channel;
  pinMapADCVOLTPINin = PIN_MAP[AD_VOLT_PIN].adc_channel;
  pinMapADCCUR2PINin = PIN_MAP[AD_CUR2_PIN].adc_channel;
  adc_set_sample_rate(ADC1, accurate ? ADC_SMPR_13_5 : ADC_SMPR_1_5);
  adc_set_reg_seqlen(ADC1, 1);
  adc_set_sample_rate(ADC2, accurate ? ADC_SMPR_13_5 : ADC_SMPR_1_5);
  adc_set_reg_seqlen(ADC2, 1);
}


volatile unsigned int number_to_sum = 256;
volatile unsigned int current_summed = 0;

volatile int sampCURI, sampVOLTI, sampCUR2I, sampPWR;
volatile int sampCURQ, sampVOLTQ, sampCUR2Q;

volatile short sampCUR, sampVOLT, sampCUR2;

unsigned short analogReadPins(void)
{
  ADC1->regs->SQR3 = pinMapADCCURPINin;
  ADC1->regs->CR2 |= ADC_CR2_SWSTART;
  ADC2->regs->SQR3 = pinMapADCVOLTPINin;
  ADC2->regs->CR2 |= ADC_CR2_SWSTART;

  while (!(ADC1->regs->SR & ADC_SR_EOC));
  sampCUR = (ADC1->regs->DR & ADC_DR_DATA);

  ADC1->regs->SQR3 = pinMapADCCUR2PINin;
  ADC1->regs->CR2 |= ADC_CR2_SWSTART;

  while (!(ADC2->regs->SR & ADC_SR_EOC));
  sampVOLT = (ADC2->regs->DR & ADC_DR_DATA);

  while (!(ADC1->regs->SR & ADC_SR_EOC));
  sampCUR2 = (ADC1->regs->DR & ADC_DR_DATA);
}

void setup_pins(void)
{
  afio_cfg_debug_ports(AFIO_DEBUG_SW_ONLY); // release PB3 and PB5

  pinMode(ATTEN_PIN, OUTPUT);
  digitalWrite(ATTEN_PIN, LOW);
  pinMode(IFCLOCK_PIN, INPUT);
  pinMode(IFCLOCK_PORT2_PIN, INPUT);
  pinMode(AD_CUR_PIN, INPUT_ANALOG);
  pinMode(AD_VOLT_PIN, INPUT_ANALOG);
  pinMode(AD_CUR2_PIN, INPUT_ANALOG);
#ifdef VNA_TOUCHSCREEN
  pinMode(TOUCHSCREEN_DISABLE_PIN, INPUT_PULLUP);
  delay(1);
  touchscreen_enabled = digitalRead(TOUCHSCREEN_DISABLE_PIN) == HIGH;
#endif
}

#define DEMCR           (*((volatile uint32_t *)0xE000EDFC))
#define DWT_CTRL        (*(volatile uint32_t *)0xe0001000)
#define CYCCNTENA       (1<<0)
#define DWT_CYCCNT      ((volatile uint32_t *)0xE0001004)
#define CPU_CYCLES      *DWT_CYCCNT
#define DEMCR_TRCENA    0x01000000

static void initialize_cortex_m3_cycle_counter(void)
{
  DEMCR |= DEMCR_TRCENA;
  *DWT_CYCCNT = 0;
  DWT_CTRL |= CYCCNTENA;
}

volatile unsigned int lasttick = 0;
volatile unsigned int numphases = 4;
volatile unsigned int curphase = 0;

void ifClockInterrupt(void)
{
  unsigned int timerval = CPU_CYCLES;
  unsigned int diftick = ((unsigned int)(timerval - lasttick));
  lasttick = timerval;

  if (current_summed <= number_to_sum)
  {
    if (current_summed == 0)
    {
      sampCURI = 0; sampCURQ = 0;
      sampVOLTI = 0; sampVOLTQ = 0;
      sampCUR2I = 0; sampCUR2Q = 0;
      sampPWR = 0;
    }
    current_summed++;
    if (current_summed == 1) return;
    timer_pause(PACETIMER);
    timer_set_count(PACETIMER, 0);
    if (current_summed > number_to_sum)
      return;
    timerval = diftick / numphases;
    if (timerval > (F_CPU / 200000u))
    {
      timer_set_reload(PACETIMER, timerval);
      //    timer_set_compare(PACETIMER,1,0);
      timer_generate_update(PACETIMER);
      curphase = 0;
      timer_resume(PACETIMER);
    }
  }
}

void timerContInterrupt(void)
{
  if (curphase < numphases)
  {
    analogReadPins();
    switch (curphase & 0x03)
    {
      case 0: sampCURI += sampCUR;
        sampVOLTI += sampVOLT;
        sampCUR2I += sampCUR2;
        break;
      case 1: sampCURQ -= sampCUR;
        sampVOLTQ -= sampVOLT;
        sampCUR2Q -= sampCUR2;
        break;
      case 2: sampCURI -= sampCUR;
        sampVOLTI -= sampVOLT;
        sampCUR2I -= sampCUR2;
        break;
      case 3: sampCURQ += sampCUR;
        sampVOLTQ += sampVOLT;
        sampCUR2Q += sampCUR2;
        break;
    }
    sampPWR += sampCUR2;
    curphase++;
  }
}

void setup_if_clock(void)
{
  nvic_irq_set_priority(NVIC_EXTI_9_5, 2);
  attachInterrupt(IFCLOCK_PIN, ifClockInterrupt, FALLING);

  nvic_irq_set_priority(PACETIMER_NVIC, 2);
  timer_init(PACETIMER);
  timer_attach_interrupt(PACETIMER, 1, timerContInterrupt);
}

void vna_setup_remote_serial(void)
{
  console_setExternalSerial(vna_state.remote ? &Serial1 : NULL);
}

void setup() {
  initialize_cortex_m3_cycle_counter();
  setup_pins();

  flash_mount_fs_card();
  usb_init_serial();

  Serial1.begin(38400);
  vna_initialize_si5351();

#ifdef VNA_TOUCHSCREEN
  tcal.iscal = false;
  if (touchscreen_enabled) touchscreen_setup();
#endif

  setup_if_clock();
  setup_analog(0);
  vna_setup_remote_serial();
  vna_readcal(1);
}

void reset_calib_state(void)
{
  if (vna_1pt != NULL) free(vna_1pt);
  vna_1pt = NULL;
  vna_state.calib_state = VNA_NO_CALIB;
}

void free_calib_memory(void)
{
  if (vna_1pt != NULL) free(vna_1pt);
  vna_1pt = NULL;
  vna_state.calib_state &= ~VNA_ALL_1PT;
}

int setup_frequency_acquire(unsigned int frequency)
{
  if ((frequency < VNA_MIN_FREQ) || (frequency > VNA_MAX_FREQ))
    return -1;

  si5351.output_enable(SI5351_CLK0, 0);
#ifdef SI5351_SINGLE
  si5351.output_enable(SI5351_CLK1, 0);
#else
  si5351b.output_enable(SI5351_CLK0, 0);
#endif
  if (frequency < VNA_FREQ_3X)
  {
    si5351.set_freq(frequency * SI5351_FREQ_MULT, SI5351_CLK0);
#ifdef SI5351_SINGLE
    si5351.set_freq((frequency + VNA_NOMINAL_1X_IF_FREQ) * SI5351_FREQ_MULT, SI5351_CLK1);
#else
    si5351b.set_freq((frequency + VNA_NOMINAL_1X_IF_FREQ) * SI5351_FREQ_MULT, SI5351_CLK0);
#endif
    numphases = 4;
  } else if (frequency < VNA_FREQ_5X)
  {
    frequency = frequency / 3;
    si5351.set_freq(frequency * SI5351_FREQ_MULT, SI5351_CLK0);
#ifdef SI5351_SINGLE
    si5351.set_freq((frequency + VNA_NOMINAL_3X_IF_FREQ) * SI5351_FREQ_MULT, SI5351_CLK1);
#else
    si5351b.set_freq((frequency + VNA_NOMINAL_3X_IF_FREQ) * SI5351_FREQ_MULT, SI5351_CLK0);
#endif
    numphases = 12;
  } else if (frequency < VNA_FREQ_7X)
  {
    frequency = frequency / 5;
    si5351.set_freq(frequency * SI5351_FREQ_MULT, SI5351_CLK0);
#ifdef SI5351_SINGLE
    si5351.set_freq((frequency + VNA_NOMINAL_5X_IF_FREQ) * SI5351_FREQ_MULT, SI5351_CLK1);
#else
    si5351b.set_freq((frequency + VNA_NOMINAL_5X_IF_FREQ) * SI5351_FREQ_MULT, SI5351_CLK0);
#endif
    numphases = 20;
  } else 
  {
    frequency = frequency / 7;
    si5351.set_freq(frequency * SI5351_FREQ_MULT, SI5351_CLK0);
#ifdef SI5351_SINGLE
    si5351.set_freq((frequency + VNA_NOMINAL_7X_IF_FREQ) * SI5351_FREQ_MULT, SI5351_CLK1);
#else
   si5351b.set_freq((frequency + VNA_NOMINAL_7X_IF_FREQ) * SI5351_FREQ_MULT, SI5351_CLK0);
#endif
    numphases = 28;
  }  
  delay(2);
  si5351.output_enable(SI5351_CLK0, 1);
#ifdef SI5351_SINGLE
  si5351.output_enable(SI5351_CLK1, 1);
#else
  si5351b.output_enable(SI5351_CLK0, 1);
#endif
  digitalWrite(ATTEN_PIN, vna_state.atten ? HIGH : LOW);
  return 0;
}

void vna_initialize_si5351()
{
#ifdef SI5351_SINGLE
  si5351.init(SI5351_CRYSTAL_LOAD_8PF, 25000000u, 0);
  si5351.drive_strength(SI5351_CLK0, SI5351_DRIVE_6MA);
  si5351.drive_strength(SI5351_CLK1, SI5351_DRIVE_6MA);
  si5351.set_ms_source(SI5351_CLK0, SI5351_PLLA);
  si5351.set_ms_source(SI5351_CLK1, SI5351_PLLB);
#else
  si5351.init(SI5351_CRYSTAL_LOAD_8PF, 25000000u, 0);
  si5351.drive_strength(SI5351_CLK0, SI5351_DRIVE_6MA);
  si5351.drive_strength(SI5351_CLK2, SI5351_DRIVE_6MA);
  si5351.set_ms_source(SI5351_CLK0, SI5351_PLLA);
  si5351.set_ms_source(SI5351_CLK1, SI5351_PLLB);
  si5351.set_ms_source(SI5351_CLK2, SI5351_PLLB);
  si5351.set_freq(25000001ull * SI5351_FREQ_MULT, SI5351_CLK2);
  si5351b.init(SI5351_CRYSTAL_LOAD_8PF, 25000000u, 0);
  si5351b.drive_strength(SI5351_CLK0, SI5351_DRIVE_6MA);
  si5351b.set_ms_source(SI5351_CLK0, SI5351_PLLA);
#endif
}

vna_acquire_current_state vna_operation_acquire_dataset(vna_acquire_state *vas)
{
  vna_acquisition_state *vs = vas->vs;
  unsigned int freq = vs->startfreq + vas->freqstep * vas->n;

  if (vas->vacs == VNA_ACQUIRE_RECORDED_STATE)
  {
    number_to_sum = 0;
    if (vas->wait_for_end)
    {
      setup_frequency_acquire(freq);
      timer_pause(PACETIMER);
      timer_attach_interrupt(PACETIMER, 1, timerContInterrupt);
      timer_set_prescaler(PACETIMER, 0);
      timer_set_mode(PACETIMER, 1, TIMER_OUTPUT_COMPARE);
      timer_set_count(PACETIMER, 0);
      timer_set_reload(PACETIMER, 65535);
      timer_set_compare(PACETIMER, 1, 0);
      timer_generate_update(PACETIMER);
    }
    vas->vacs = VNA_ACQUIRE_RECORDED_STATE_WAITING;
    vas->inittime = CPU_CYCLES;
    current_summed = 0;
    number_to_sum = vas->wait_for_end ? 12 : vs->num_averages;
  }
  if (vas->vacs != VNA_ACQUIRE_RECORDED_STATE_WAITING)
    return vas->vacs;
  if (current_summed <= number_to_sum)
  {
    unsigned int curtime = CPU_CYCLES;
    if (((unsigned int)(curtime - vas->inittime)) > vas->timeout)
      vas->vacs = VNA_ACQUIRE_TIMEOUT;
    return vas->vacs;
  }
  if (vas->wait_for_end)
  {
    vas->wait_for_end = false;
    vas->vacs = VNA_ACQUIRE_RECORDED_STATE;
    return vas->vacs;
  }
  if (vas->vado != NULL)
  {
    vna_acquire_dataset_state vads;
    vads.n = vas->n;
    vads.total = vs->nfreqs;
    vads.freq = freq;
    vads.volti = sampVOLTI;
    vads.voltq = sampVOLTQ;
    vads.curi = sampCURI;
    vads.curq = sampCURQ;
    vads.cur2i = sampCUR2I;
    vads.cur2q = sampCUR2Q;
    vas->vado(&vads, vas->vado_v);
  }
  vas->n++;
  if (vas->n >= vs->nfreqs)
  {
    vas->vacs = VNA_ACQUIRE_COMPLETE;
    return vas->vacs;
  }
  if (vas->check_interruption)
  {
    if (console_inchar() == '!')
    {
      vas->vacs = VNA_ACQUIRE_ABORT;
      return vas->vacs;
    }
#ifdef VNA_TOUCHSCREEN
    if (touchscreen_enabled && touchscreen_abort())
    {
      vas->vacs = VNA_ACQUIRE_ABORT;
      return vas->vacs;
    }
#endif
  }
  vas->wait_for_end = true;
  vas->vacs = VNA_ACQUIRE_RECORDED_STATE;
  return vas->vacs;
}

vna_acquire_current_state vna_setup_acquire_dataset(vna_acquire_state *vas, vna_acquisition_state *vs, vna_acquire_dataset_operation vado, void *v)
{
  number_to_sum = 0;
  vas->vs = vs;
  vas->wait_for_end = true;
  vas->n = 0;
  vas->vado = vado;
  vas->vado_v = v;
  vas->timeout = vs->timeout * (F_CPU / 1000u);
  vas->freqstep = (vs->endfreq - vs->startfreq) / vs->nfreqs;
  vas->vacs = VNA_ACQUIRE_RECORDED_STATE;
  vas->check_interruption = true;
  vna_initialize_si5351();
  pinMode(AD_CUR_PIN, INPUT_ANALOG);
  pinMode(AD_VOLT_PIN, INPUT_ANALOG);
  pinMode(AD_CUR2_PIN, INPUT_ANALOG);
  return vas->vacs;
}

bool vna_acquire_dataset(vna_acquisition_state *vs, vna_acquire_dataset_operation vado, void *v)
{
  vna_acquire_state vas;

  vna_setup_acquire_dataset(&vas, vs, vado, v);
  do
  {
    vna_operation_acquire_dataset(&vas);
  } while ((vas.vacs != VNA_ACQUIRE_TIMEOUT) && (vas.vacs != VNA_ACQUIRE_ABORT) && (vas.vacs != VNA_ACQUIRE_COMPLETE));
  return (vas.vacs == VNA_ACQUIRE_COMPLETE);
}

int vna_set_averages(unsigned short averages, unsigned short timeout)
{
  if ((averages >= 1) && (averages <= 50000))
    vna_state.num_averages = averages;
  if ((timeout >= 1) && (timeout <= 50000))
    vna_state.timeout = timeout < 500 ? 500 : timeout;
  return 1;
}

int vna_set_characteristic_impedance(unsigned int char_impedance)
{
  if ((char_impedance >= 1) && (char_impedance <= 100000u))
    vna_state.char_impedance = char_impedance;
  return 1;
}

int averages_cmd(int args, tinycl_parameter* tp, void *v)
{
  vna_set_averages(tp[0].ti.i, tp[1].ti.i);
  console_print("Averages=");
  console_println(vna_state.num_averages);
  console_print("Timeout=");
  console_println(vna_state.timeout);
  return 1;
}

int csv_cmd(int args, tinycl_parameter* tp, void *v)
{
  int n;
  vna_acquisition_state *vs = &vna_state;
  vs->csv = tp[0].ti.i;
  console_print("CSV=");
  console_println(vs->csv);
  return 1;
}

int debug_cmd(int args, tinycl_parameter* tp, void *v)
{
  int n;
  setDebugMsgMode(tp[0].ti.i);
  console_print("DEBUG=");
  console_println(debugmsg_state);
  return 1;
}

int remote_serial_cmd(int args, tinycl_parameter* tp, void *v)
{
  int n;
  vna_acquisition_state *vs = &vna_state;
  vs->remote = tp[0].ti.i;
  console_print("remote=");
  console_println(vs->remote);
  vna_setup_remote_serial();
  return 1;
}

const char *atten_strings[3] = { "0 Off", "1 On" };

int atten_cmd(int args, tinycl_parameter* tp, void *v)
{
  int n = tp[0].ti.i;

  if ((n < 0) || (n > 1))
  {
    console_println("Invalid setting");
    return 1;
  }
  vna_state.atten = n;
  console_print("atten=");
  console_println(atten_strings[vna_state.atten]);
  return 1;
}

const char *series_shunt_strings[3] = { "0 Series", "1 Shunt" };

int shunt_cmd(int args, tinycl_parameter* tp, void *v)
{
  int n = tp[0].ti.i;

  if ((n < 0) || (n > 1))
  {
    console_println("Invalid setting");
    return 1;
  }
  vna_state.series_shunt_two = n;
  console_print("impedance-mode=");
  console_println(series_shunt_strings[vna_state.series_shunt_two]);
  return 1;
}


int vna_display_dataset_operation(vna_acquire_dataset_state *vads, void *va)
{
  if (vna_state.csv)
  {
    console_print(vads->freq);
    console_print(",");
    console_print(vads->volti);
    console_print(",");
    console_print(vads->voltq);
    console_print(",");
    console_print(vads->curi);
    console_print(",");
    console_print(vads->curq);
    console_print(",");
    console_print(vads->cur2i);
    console_print(",");
    console_println(vads->cur2q);
  } else
  {
    console_print("Freq ");
    console_print(vads->freq);
    console_print(": Volt (");
    console_print(vads->volti);
    console_print(",");
    console_print(vads->voltq);
    console_print(") Cur1 (");
    console_print(vads->curi);
    console_print(",");
    console_print(vads->curq);
    console_print(") Cur2 (");
    console_print(vads->cur2i);
    console_print(",");
    console_print(vads->cur2q);
    console_println(")");
  }
}

int doacq_cmd(int args, tinycl_parameter* tp, void *v)
{
  int n;
  vna_acquisition_state *vs = &vna_state;
  vna_acquire_dataset(vs, vna_display_dataset_operation, NULL);
  return 1;
}

int vna_calset_frequencies(unsigned int nfreqs, unsigned int startfreq, unsigned int endfreq)
{
  startfreq = ((startfreq + 500u) / 1000u) * 1000u;
  endfreq = ((endfreq + 500u) / 1000u) * 1000u;
  if ((startfreq >= VNA_MIN_FREQ) && (endfreq > startfreq) && (endfreq <= VNA_MAX_FREQ))
  {
    vna_state.cal_startfreq = startfreq;
    vna_state.cal_endfreq = endfreq;
  } else return 0;
  if ((nfreqs >= 1) && (nfreqs <= VNA_MAX_CAL_FREQS)) vna_state.cal_nfreqs = nfreqs;
  else return 0;
  vna_state.startfreq = vna_state.cal_startfreq;
  vna_state.endfreq = vna_state.cal_endfreq;
  vna_state.nfreqs = vna_state.cal_nfreqs;
  reset_calib_state();
  return 1;
}

int vna_set_frequencies(unsigned int nfreqs, unsigned int startfreq, unsigned int endfreq)
{
  if ((startfreq >= vna_state.cal_startfreq) && (endfreq > startfreq) && (endfreq <= vna_state.cal_endfreq))
  {
    vna_state.startfreq = startfreq;
    vna_state.endfreq = endfreq;
  } else return 0;
  if ((nfreqs >= 1) && (nfreqs <= VNA_MAX_ACQ_FREQS)) vna_state.nfreqs = nfreqs;
  else return 0;
  return 1;
}

int setcal_cmd(int args, tinycl_parameter* tp, void *v)
{
  unsigned int nfreqs = tp[0].ti.i;
  unsigned int startfreq = tp[1].ti.i;
  unsigned int endfreq = tp[2].ti.i;
  bool statereset = (vna_state.calib_state != VNA_NO_CALIB);
  if (!vna_calset_frequencies(nfreqs, startfreq, endfreq))
  {
    console_println("Invalid Parameters");
    return 1;
  }
  console_print("Cal Start Frequency = ");
  console_println(vna_state.startfreq);
  console_print("Cal End Frequency = ");
  console_println(vna_state.endfreq);
  console_print("Cal Number Frequencies = ");
  console_println(vna_state.nfreqs);
  if (statereset)
    console_println("Calibration state reset");
  return 1;
}

int setacq_cmd(int args, tinycl_parameter* tp, void *v)
{
  unsigned int nfreqs = tp[0].ti.i;
  unsigned int startfreq = tp[1].ti.i;
  unsigned int endfreq = tp[2].ti.i;
  if (!vna_set_frequencies(nfreqs, startfreq, endfreq))
  {
    console_println("Invalid Parameters");
    return 1;
  }
  console_print("Start Frequency = ");
  console_println(vna_state.startfreq);
  console_print("End Frequency = ");
  console_println(vna_state.endfreq);
  console_print("Number Frequencies = ");
  console_println(vna_state.nfreqs);
  return 1;
}

int imacq_cmd(int args, tinycl_parameter* tp, void *v)
{
  vna_acquisition_state vs = vna_state;
  vs.nfreqs = tp[0].ti.i;
  vs.startfreq = tp[1].ti.i;
  vs.endfreq = tp[2].ti.i;
  if (vs.nfreqs < 1)
  {
    console_println("Invalid number of frequencies");
    return 1;
  }
  if ((vs.startfreq < VNA_MIN_FREQ) || (vs.endfreq < vs.startfreq) && (vs.endfreq > VNA_MAX_FREQ))
  {
    console_println("Invalid maximum or minimum frequency");
    return 1;
  }
  vna_acquire_dataset(&vs, vna_display_dataset_operation, NULL);
  return 1;
}

int vna_open_dataset_operation(vna_acquire_dataset_state *vads, void *va)
{
  vna_calib_oneport *v1pt = (vna_calib_oneport *)va;
  v1pt[vads->n].zo = Complex((float)vads->volti, (float)vads->voltq) / Complex((float)vads->curi, (float)vads->curq);
  if (debugmsg_state)
  {
    char s[80];
    mini_snprintf(s, sizeof(s) - 1, "Open freq %u zo=%06f + j%06f", vads->freq, float2int32(v1pt[vads->n].zo.real), float2int32(v1pt[vads->n].zo.imag));
    console_println(s);
  }
}

int vna_short_dataset_operation(vna_acquire_dataset_state *vads, void *va)
{
  vna_calib_oneport *v1pt = (vna_calib_oneport *)va;
  v1pt[vads->n].zs = Complex((float)vads->volti, (float)vads->voltq) / Complex((float)vads->curi, (float)vads->curq);
  if (debugmsg_state)
  {
    char s[80];
    mini_snprintf(s, sizeof(s) - 1, "Short freq %u zs=%06f + j%06f", vads->freq, float2int32(v1pt[vads->n].zs.real), float2int32(v1pt[vads->n].zs.imag));
    console_println(s);
  }
}

int vna_load_dataset_operation(vna_acquire_dataset_state *vads, void *va)
{
  vna_calib_oneport *v1pt = (vna_calib_oneport *)va;
  v1pt[vads->n].zt = Complex((float)vads->volti, (float)vads->voltq) / Complex((float)vads->curi, (float)vads->curq);
  vna_calib[vads->n].s2 = Complex((float)vads->cur2i, (float)vads->cur2q) / ((float) vna_state.num_averages);
  if (debugmsg_state)
  {
    char s[80];
    mini_snprintf(s, sizeof(s) - 1, "Load freq %u zt=%06f + j%06f", vads->freq, float2int32(v1pt[vads->n].zt.real), float2int32(v1pt[vads->n].zt.imag));
    console_println(s);
  }
}

int vna_allocate_1pt_calib(void)
{
  if (vna_1pt != NULL) return 1;
  if ((vna_1pt = (vna_calib_oneport *) malloc(sizeof(vna_calib_oneport) * vna_state.cal_nfreqs)) == NULL)
  {
    vna_state.calib_state = VNA_NO_CALIB;
    return 0;
  }
  return 1;
}

int vna_complete_1pt_calib(void)
{
  int n;

  if ((vna_state.calib_state & VNA_ALL_1PT) != VNA_ALL_1PT)
    return 0;
  if (vna_1pt == NULL) return 0;
  float z0 = vna_state.char_impedance;
  for (n = 0; n < vna_state.cal_nfreqs; n++)
  {
    vna_calib_freq_parm *vc = &vna_calib[n];
    vc->b = -vna_1pt[n].zs;
    vc->c = (vna_1pt[n].zs - vna_1pt[n].zt) / ((vna_1pt[n].zo - vna_1pt[n].zt) * z0);
    vc->d = (-vna_1pt[n].zo) * vc->c;
  }
  vna_state.calib_state |= VNA_VALID_CALIB_1PT;
  vna_state.calib_state &= ~VNA_VALID_CALIB_2PT;
  free_calib_memory();
  return 1;
}

void vna_set_calib_acquisition_state(vna_acquisition_state *vs)
{
  *vs = vna_state;
  vs->nfreqs = vna_state.cal_nfreqs;
  vs->startfreq = vna_state.cal_startfreq;
  vs->endfreq = vna_state.cal_endfreq;
}

int vna_opencalib(void)
{
  vna_acquisition_state vs;
  vna_set_calib_acquisition_state(&vs);
  if (!vna_allocate_1pt_calib()) return 0;
  if (!vna_acquire_dataset(&vs, vna_open_dataset_operation, (void *)vna_1pt)) return 0;
  vna_state.calib_state |= VNA_OPEN_CALIB;
  return vna_complete_1pt_calib() ? 2 : 1;
}
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
void loop(void)
{
  if (tinycl_task(sizeof(tcmds) / sizeof(tinycl_command), tcmds, NULL))
  {
    tinycl_do_echo = 1;
    console_print("> ");
  }
#ifdef VNA_TOUCHSCREEN
  if (touchscreen_enabled) touchscreen_task();
#endif
}

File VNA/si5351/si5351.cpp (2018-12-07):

/*
 * si5351.cpp - Si5351 library for Arduino
 *
 * Copyright (C) 2015 - 2016 Jason Milldrum <milldrum@gmail.com>
 *                           Dana H. Myers <k6jq@comcast.net>
 *
 * Some tuning algorithms derived from clk-si5351.c in the Linux kernel.
 * Sebastian Hesselbarth <sebastian.hesselbarth@gmail.com>
 * Rabeeh Khoury <rabeeh@solid-run.com>
 *
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
 * You should have received a copy of the GNU General Public License
 * along with this program.  If not, see <http://www.gnu.org/licenses/>.
 */

#include <stdint.h>

#include "Arduino.h"
#include "Wire.h"
#include "si5351.h"


/********************/
/* Public functions */
/********************/

Si5351::Si5351(uint8_t i2c_addr):
	i2c_bus_addr(i2c_addr)
{
	xtal_freq[0] = SI5351_XTAL_FREQ;

	// Start by using XO ref osc as default for each PLL
	plla_ref_osc = SI5351_PLL_INPUT_XO;
	pllb_ref_osc = SI5351_PLL_INPUT_XO;
	clkin_div = SI5351_CLKIN_DIV_1;
}

/*
 * init(uint8_t xtal_load_c, uint32_t ref_osc_freq, int32_t corr)
 *
 * Setup communications to the Si5351 and set the crystal
 * load capacitance.
 *
 * xtal_load_c - Crystal load capacitance. Use the SI5351_CRYSTAL_LOAD_*PF
 * defines in the header file
 * xo_freq - Crystal/reference oscillator frequency in 1 Hz increments.
 * Defaults to 25000000 if a 0 is used here.
 * corr - Frequency correction constant in parts-per-billion
 *
 * Returns a boolean that indicates whether a device was found on the desired
 * I2C address.
 *
 */
bool Si5351::init(uint8_t xtal_load_c, uint32_t xo_freq, int32_t corr)
{
	// Start I2C comms
	Wire.begin();

	// Check for a device on the bus, bail out if it is not there
	Wire.beginTransmission(i2c_bus_addr);
	uint8_t reg_val;
  reg_val = Wire.endTransmission();

	if(reg_val == 0)
	{
		// Wait for SYS_INIT flag to be clear, indicating that device is ready
		uint8_t status_reg = 0;
		do
		{
			status_reg = si5351_read(SI5351_DEVICE_STATUS);
		} while (status_reg >> 7 == 1);

		// Set crystal load capacitance
		si5351_write(SI5351_CRYSTAL_LOAD, (xtal_load_c & SI5351_CRYSTAL_LOAD_MASK) | 0b00010010);

		// Set up the XO reference frequency
		if (xo_freq != 0)
		{
			set_ref_freq(xo_freq, SI5351_PLL_INPUT_XO);
		}
		else
		{
			set_ref_freq(SI5351_XTAL_FREQ, SI5351_PLL_INPUT_XO);
		}

		// Set the frequency calibration for the XO
		set_correction(corr, SI5351_PLL_INPUT_XO);

		reset();

		return true;
	}
	else
	{
		return false;
	}
}

/*
 * reset(void)
 *
 * Call to reset the Si5351 to the state initialized by the library.
 *
 */
void Si5351::reset(void)
{
	// Initialize the CLK outputs according to flowchart in datasheet
	// First, turn them off
	si5351_write(16, 0x80);
	si5351_write(17, 0x80);
	si5351_write(18, 0x80);
	si5351_write(19, 0x80);
	si5351_write(20, 0x80);
	si5351_write(21, 0x80);
	si5351_write(22, 0x80);
	si5351_write(23, 0x80);

	// Turn the clocks back on...
	si5351_write(16, 0x0c);
	si5351_write(17, 0x0c);
	si5351_write(18, 0x0c);
	si5351_write(19, 0x0c);
	si5351_write(20, 0x0c);
	si5351_write(21, 0x0c);
	si5351_write(22, 0x0c);
	si5351_write(23, 0x0c);

	// Set PLLA and PLLB to 800 MHz for automatic tuning
	set_pll(SI5351_PLL_FIXED, SI5351_PLLA);
	set_pll(SI5351_PLL_FIXED, SI5351_PLLB);

	// Make PLL to CLK assignments for automatic tuning
	pll_assignment[0] = SI5351_PLLA;
	pll_assignment[1] = SI5351_PLLA;
	pll_assignment[2] = SI5351_PLLA;
	pll_assignment[3] = SI5351_PLLA;
	pll_assignment[4] = SI5351_PLLA;
	pll_assignment[5] = SI5351_PLLA;
	pll_assignment[6] = SI5351_PLLB;
	pll_assignment[7] = SI5351_PLLB;

	set_ms_source(SI5351_CLK0, SI5351_PLLA);
	set_ms_source(SI5351_CLK1, SI5351_PLLA);
	set_ms_source(SI5351_CLK2, SI5351_PLLA);
	set_ms_source(SI5351_CLK3, SI5351_PLLA);
	set_ms_source(SI5351_CLK4, SI5351_PLLA);
	set_ms_source(SI5351_CLK5, SI5351_PLLA);
	set_ms_source(SI5351_CLK6, SI5351_PLLB);
	set_ms_source(SI5351_CLK7, SI5351_PLLB);

	// Reset the VCXO param
	si5351_write(SI5351_VXCO_PARAMETERS_LOW, 0);
	si5351_write(SI5351_VXCO_PARAMETERS_MID, 0);
	si5351_write(SI5351_VXCO_PARAMETERS_HIGH, 0);

	// Then reset the PLLs
	pll_reset(SI5351_PLLA);
	pll_reset(SI5351_PLLB);

	// Set initial frequencies
	uint8_t i;
	for(i = 0; i < 8; i++)
	{
		clk_freq[i] = 0;
		output_enable((enum si5351_clock)i, 0);
		clk_first_set[i] = false;
	}
}

/*
 * set_freq(uint64_t freq, enum si5351_clock clk)
 *
 * Sets the clock frequency of the specified CLK output.
 * Frequency range of 8 kHz to 150 MHz
 *
 * freq - Output frequency in Hz
 * clk - Clock output
 *   (use the si5351_clock enum)
 */
uint8_t Si5351::set_freq(uint64_t freq, enum si5351_clock clk)
{
	struct Si5351RegSet ms_reg;
	uint64_t pll_freq;
	uint8_t int_mode = 0;
	uint8_t div_by_4 = 0;
	uint8_t r_div = 0;

	// Check which Multisynth is being set
	if((uint8_t)clk <= (uint8_t)SI5351_CLK5)
	{
		// MS0 through MS5 logic
		// ---------------------

		// Lower bounds check
		if(freq > 0 && freq < SI5351_CLKOUT_MIN_FREQ * SI5351_FREQ_MULT)
		{
			freq = SI5351_CLKOUT_MIN_FREQ * SI5351_FREQ_MULT;
		}

		// Upper bounds check
		if(freq > SI5351_MULTISYNTH_MAX_FREQ * SI5351_FREQ_MULT)
		{
			freq = SI5351_MULTISYNTH_MAX_FREQ * SI5351_FREQ_MULT;
		}

		// If requested freq >100 MHz and no other outputs are already >100 MHz,
		// we need to recalculate PLLA and then recalculate all other CLK outputs
		// on same PLL
		if(freq > (SI5351_MULTISYNTH_SHARE_MAX * SI5351_FREQ_MULT))
		{
			// Check other clocks on same PLL
			uint8_t i;
			for(i = 0; i < 6; i++)
			{
				if(clk_freq[i] > (SI5351_MULTISYNTH_SHARE_MAX * SI5351_FREQ_MULT))
				{
					if(i != (uint8_t)clk && pll_assignment[i] == pll_assignment[clk])
					{
						return 1; // won't set if any other clks already >100 MHz
					}
				}
			}

			// Enable the output on first set_freq only
			if(clk_first_set[(uint8_t)clk] == false)
			{
				output_enable(clk, 1);
				clk_first_set[(uint8_t)clk] = true;
			}

			// Set the freq in memory
			clk_freq[(uint8_t)clk] = freq;

			// Calculate the proper PLL frequency
			pll_freq = multisynth_calc(freq, 0, &ms_reg);

			// Set PLL
			set_pll(pll_freq, pll_assignment[clk]);

			// Recalculate params for other synths on same PLL
			for(i = 0; i < 6; i++)
			{
				if(clk_freq[i] != 0)
				{
					if(pll_assignment[i] == pll_assignment[clk])
					{
						struct Si5351RegSet temp_reg;
						uint64_t temp_freq;

						// Select the proper R div value
						temp_freq = clk_freq[i];
						r_div = select_r_div(&temp_freq);

						multisynth_calc(temp_freq, pll_freq, &temp_reg);

						// If freq > 150 MHz, we need to use DIVBY4 and integer mode
						if(temp_freq >= SI5351_MULTISYNTH_DIVBY4_FREQ * SI5351_FREQ_MULT)
						{
							div_by_4 = 1;
							int_mode = 1;
						}
						else
						{
							div_by_4 = 0;
							int_mode = 0;
						}

						// Set multisynth registers
						set_ms((enum si5351_clock)i, temp_reg, int_mode, r_div, div_by_4);
					}
				}
			}

			// Reset the PLL
			pll_reset(pll_assignment[clk]);
		}
		else
		{
			clk_freq[(uint8_t)clk] = freq;
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

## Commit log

2018-10-07 Made continuous ground plane over most of the part
    [VNA-B.Cu.gbr, VNA-B.Mask.gbr, VNA-B.SilkS.gbr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]
2018-11-07 Removed useless parts of the board and make some corrections
    [VNA-B.Cu.gbr, VNA-B.Mask.gbr, VNA-B.SilkS.gbr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]
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2018-11-20 Substitute LM339 for 74HC14
    [VNA-B.Cu.gbr, VNA-B.Mask.gbr, VNA-B.SilkS.gbr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]
2018-11-27 Working 1 and 2 port calibration
    [VNA-B.Cu.gbr, VNA-B.Mask.gbr, VNA-B.SilkS.gbr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]
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2018-12-07 Load and Save on Flash
    [VNA BOM.ods, VNA.sch, VNA2.sch]
2018-12-10 Working save to flash, 1 and 2 port, new design
    [VNA.sch]
2018-12-10 Sign error mistake in phase
    [VNA.ino]
2018-12-12 Clarified copyright of PCB, CC-BY-SA 4.0 and code which is zlib
    [VNA-B.Cu.gbr, VNA-B.Mask.gbr, VNA-B.SilkS.gbr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]
2018-12-20 Added some more CS pins to header
    [VNA-B.Cu.gbr, VNA-B.Mask.gbr, VNA-B.SilkS.gbr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]
2018-12-21 Added Smith Chart plot
    [VNA.sch]
2018-12-22 Changed TL082 to LM358, other corrections to software
    [VNA-B.Cu.gbr, VNA-B.Mask.gbr, VNA-B.SilkS.gbr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]
2018-12-24 A few minor fixes, grounding, etc.
    [VNA-B.Cu.gbr, VNA-B.Mask.gbr, VNA-B.SilkS.gbr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]
2018-12-26 Added attenuation option to touchscreen, fixed attenuation resistors
    [VNA.sch]
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2018-12-29 Added surface mount version
    [VNA BOM.ods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]
2018-12-29 Fixed a label
    [VNA-B.Cu.gbr, VNA-B.Mask.gbr, VNA-B.SilkS.gbr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]
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2019-01-06 Added support for minimal minivna compatibility
    [VNA-B.Cu.gbr, VNA-B.Mask.gbr, VNA-B.SilkS.gbr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]
2019-01-15 Reset PLL before each frequency change for maximum repeatability
    [VNA.ino]
2019-05-19 Removed unneded file from board-smit
    [VNA-NPTH.drl]
2019-07-03 Changed SMA connector, added dual power option for LCD
    [VNA-B.Cu.gbr, VNA-B.Mask.gbr, VNA-B.SilkS.gbr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]
2019-07-13 Turned a voltage regulator around
    [VNA-B.Cu.gbr, VNA-B.Mask.gbr, VNA-B.SilkS.gbr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]
2019-09-30 Increased isolation between ports
    [VNA-B.Cu.gbr, VNA-B.Mask.gbr, VNA-B.SilkS.gbr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]
2019-09-30 Mask removal on wrong layer
    [VNA-B.Cu.gbr, VNA-B.Mask.gbr, VNA-B.SilkS.gbr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]
2019-10-02 Rearranged some more to reduce crosstalk
    [VNA-B.Cu.gbr, VNA-B.Mask.gbr, VNA-B.SilkS.gbr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]
2019-10-02 Added even more isolation
    [VNA-B.Cu.gbr, VNA-B.Mask.gbr, VNA-B.SilkS.gbr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]
2019-10-02 Added ferrite beads to serial connection
    [VNA-B.Cu.gbr, VNA-B.Mask.gbr, VNA-B.SilkS.gbr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]
2019-10-02 Rearranged for shorter high frequency traces
    [VNA-B.Cu.gbr, VNA-B.Mask.gbr, VNA-B.SilkS.gbr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]
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2019-10-10 Added extra outputs to connector, changed display off pin
    [VNA-B.Cu.gbr, VNA-B.Mask.gbr, VNA-B.SilkS.gbr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]
2019-10-23 Daughterboard added for jog wheel and buttons
    [VNA-B.Cu.gbr, VNA-B.Mask.gbr, VNA-B.SilkS.gbr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]
2019-10-23 Added daughterboard for mounting LCD and jog wheel
    [daughterboard-B.Cu.gbr, daughterboard-B.Mask.gbr, daughterboard-B.SilkS.gbr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]
2019-10-23 Created fixture PCB for calibration and component testing
    [fixture-B.Cu.gbr, fixture-B.Mask.gbr, fixture-B.SilkS.gbr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]
2019-10-23 Added area around open circuit without copper fill
    [fixture-B.Cu.gbr, fixture-B.Mask.gbr, fixture-B.SilkS.gbr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]
2019-10-23 Oops forgot to fill under screw clamp
    [fixture-B.Cu.gbr, fixture-B.Mask.gbr, fixture-B.SilkS.gbr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]
2019-10-23 Made more room for handle of ZIF socket
    [fixture-B.Cu.gbr, fixture-B.Mask.gbr, fixture-B.SilkS.gbr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]
2019-10-23 Moved mounting holes to ensure no interference
    [daughterboard-B.Cu.gbr, daughterboard-B.Mask.gbr, daughterboard-B.SilkS.gbr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]
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2019-10-23 Added resistors in discharge debounce
    [daughterboard-B.Cu.gbr, daughterboard-B.Mask.gbr, daughterboard-B.SilkS.gbr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]
2019-10-23 Changed fixture to use toggle clamp
    [fixture-B.Cu.gbr, fixture-B.Mask.gbr, fixture-B.SilkS.gbr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]
2019-10-26 Added vacuum holes to fixture
    [VNA-B.Cu.gbr, VNA-B.Mask.gbr, VNA-B.SilkS.gbr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]
2019-10-26 Added many features:
    Calibration frequencies now separate from scan frequencies
    Bigger buttons
    Sideways Text in graphs
    Graphs now have a longer marker line
    [fixture-NPTH.drl]
2019-10-27 Moved the SI5351A even closer
    [VNA-B.Cu.gbr, VNA-B.Mask.gbr, VNA-B.SilkS.gbr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]
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2019-11-09 Modified fixture for larger holes for ZIF socket
    [fixture-B.Cu.gbr, fixture-B.Mask.gbr, fixture-B.SilkS.gbr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]
2019-11-11 Added jogwheel and sweep, simplified daughterboard
    [daughterboard-B.Cu.gbr, daughterboard-B.Mask.gbr, daughterboard-B.SilkS.gbr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]
2019-11-11 VNA-o-mizer is rechristened, added two files jogwheel.*
    [VNA-B.Cu.gbr, VNA-B.Mask.gbr, VNA-B.SilkS.gbr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]
2019-11-11 Oops changed back to TIMER2
    [VNA-B.Cu.gbr, VNA-B.Mask.gbr, VNA-B.SilkS.gbr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]
2019-11-13 Added JST 2.54 power and USB-B connecotrs
    [VNA-B.Cu.gbr, VNA-B.Mask.gbr, VNA-B.SilkS.gbr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]
2019-11-13 oops silkscreening error
    [VNA-B.Cu.gbr, VNA-B.Mask.gbr, VNA-B.SilkS.gbr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]
2019-11-14 Changed fixture loads to have less capacitance
    [VNA.kicad_pcb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]
2019-11-14 Added mt3608 boost converter for battery usage
    [VNA-B.Cu.gbr, VNA-B.Mask.gbr, VNA-B.SilkS.gbr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]
2019-11-14 100 uH in pi filter
    [VNA.sch]
2019-11-14 Rearranged the PCB, CN3502 battery charger and MT3608 boost converter on-board
    [VNA-B.Cu.gbr, VNA-B.Mask.gbr, VNA-B.SilkS.gbr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]
2019-11-16 Move components around on board, adjusted fixture, added touchscreen disables
    [VNA-B.Cu.gbr, VNA-B.Mask.gbr, VNA-B.SilkS.gbr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]
2019-11-17 Rearranged some traces on board-smt for better isolation
    [VNA-B.Cu.gbr, VNA-B.Mask.gbr, VNA-B.SilkS.gbr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]
2019-11-17 Added protection Zener diode on Pi filter to protect against ON/OFF transients
    [VNA-B.Cu.gbr, VNA-B.Mask.gbr, VNA-B.SilkS.gbr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]
2019-11-20 Added provision for separate SI5351A for LO signal
    [VNA-B.Cu.gbr, VNA-B.Mask.gbr, VNA-B.SilkS.gbr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]
2019-11-20 Cleaned up ground traces a bit
    [VNA-B.Cu.gbr, VNA-B.Mask.gbr, VNA-B.SilkS.gbr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]
2019-11-20 Slaved the second SI5351A to the first SI5351A
    [VNA-B.Cu.gbr, VNA-B.Mask.gbr, VNA-B.SilkS.gbr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]
2019-11-21 Moved jumper a little for lower parasitics
    [VNA-B.Cu.gbr, VNA-B.Mask.gbr, VNA-B.SilkS.gbr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]
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2019-11-28 Tweaked the layout on port 2
    [VNA-B.Cu.gbr, VNA-B.Mask.gbr, VNA-B.SilkS.gbr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]
2019-12-02 Fixed crystal pinout, added heatsink pad to CN3052A
    [VNA-B.Cu.gbr, VNA-B.Mask.gbr, VNA-B.SilkS.gbr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]
2019-12-02 Fixed a few more outstanding issues
    [VNA-B.Cu.gbr, VNA-B.Mask.gbr, VNA-B.SilkS.gbr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]
2019-12-05 Changed Schottky diode to SS14 and 1N4148 to BAV99
    [VNA-B.Cu.gbr, VNA-B.Mask.gbr, VNA-B.SilkS.gbr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]
2019-12-05 Added source termination resistor to LO SI5351A
    [VNA-B.Cu.gbr, VNA-B.Mask.gbr, VNA-B.SilkS.gbr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]
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2020-01-23 Changed pullup resistors to 10k for less supply noise
    [VNA.sch, VNA2.sch]
2020-01-24 Updated software to add cursor for smith chart, also changed edge of triggering
    [VNA-B.Cu.gbr, VNA-B.Mask.gbr, VNA-B.SilkS.gbr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]
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2020-05-06 Adds SD card support, which is mandatory. Also changed firmware for new pinouts.
    [VNA-B.Cu.gbr, VNA-B.Mask.gbr, VNA-B.SilkS.gbr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]
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2021-01-02 Modified some component values on bridge for better performance
    [VNA-BOM.xlsx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]

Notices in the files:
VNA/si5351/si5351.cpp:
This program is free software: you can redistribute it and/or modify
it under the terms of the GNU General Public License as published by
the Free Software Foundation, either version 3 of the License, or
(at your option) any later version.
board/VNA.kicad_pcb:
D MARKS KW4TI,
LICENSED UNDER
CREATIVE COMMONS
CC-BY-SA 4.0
